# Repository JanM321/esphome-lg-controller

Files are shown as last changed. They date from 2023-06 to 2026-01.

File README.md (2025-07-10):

# ESPHome LG AC Wired Controller
Wired controller for LG Air Conditioners using an ESP32 microcontroller and [ESPHome](https://esphome.io/). It can be used to control an indoor unit from [Home Assistant](https://www.home-assistant.io/).

This has some advantages compared to the [LG ThinQ integration](https://github.com/ollo69/ha-smartthinq-sensors):
* Can override the unit's room temperature thermistor with a Home Assistant temperature sensor.
* Does not depend on LG's ThinQ cloud service.
* Supports units without a Wifi module.
* No annoying sounds from the AC unit when changing settings through the controller.
* More settings and information available (although some settings like display light on/off are available in ThinQ but aren't passed to the wired controller).

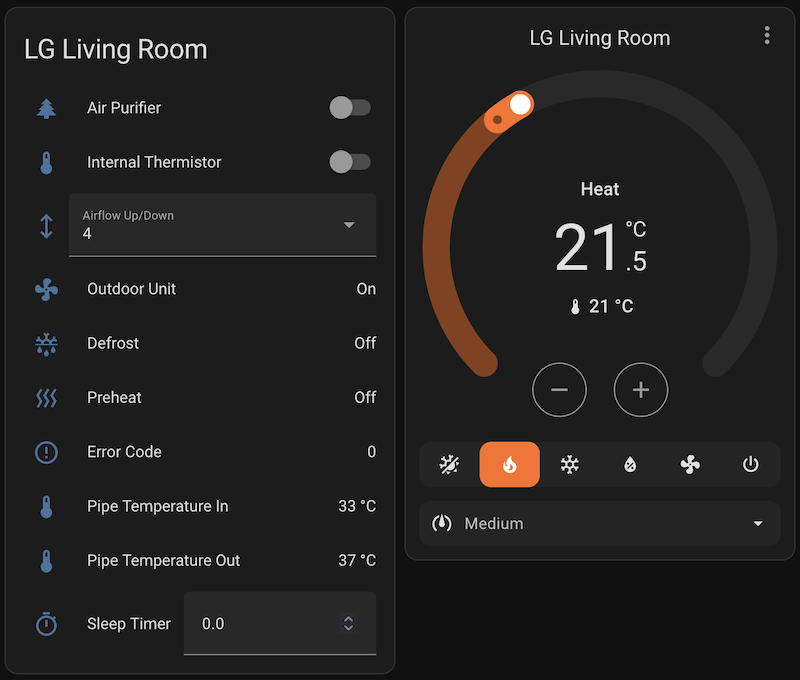
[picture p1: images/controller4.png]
Screenshot of Home Assistant dashboard


# Compatibility
### Supported AC units
If your indoor unit supports the LG PREMTB100 and/or LG PREMTA200 controller, it will very likely be compatible.

The [wiki](https://github.com/JanM321/esphome-lg-controller/wiki) has a list of LG AC units that have been tested with this controller.

### Multiple controllers
It's possible to connect multiple controllers to a single indoor unit, but one of them must be set as 'master' and the others as 'slave'. Since February 2024, this ESPHome controller has experimental support for this. I'm not using this myself, so there might be some issues with this (please report them).

The room temperature sensor is ignored for 'slave' controllers, so if you want to use this controller with an LG controller and use a Home Assistant temperature sensor, the LG controller must be set as 'slave'.

### Details
There seem to be two different protocols that LG AC units and wall controllers use to communicate: 
1. **6-byte protocol**: the controller sends a 6-byte message every four seconds or so and the AC unit responds with a 6-byte message. This is the more basic protocol and likely older because it doesn't support advanced features and settings. An ESPHome implementation of this is available here: https://github.com/Flameeyes/esphome-lg-pqrcuds0
2. **13-byte [protocol](protocol.md)**: the controller sends a 13-byte status message every 20 seconds (or when there's a change in settings) and the AC unit sends a very similar status message every 60 seconds. There are also other message types for more advanced settings. **This is the one implemented here.**

The controller hardware is identical because both use a very slow serial connection (104 bps) over a three-wire cable (Red = 12V, Yellow = Signal, Black = GND). In fact, some LG controllers support both protocols: my LG PREMTB001 controller first tries the 13-byte protocol and if it doesn't receive a response it will switch to the 6-byte protocol. My LG PREMTB100 (newer controller) only supports the 13-byte protocol as far as I can tell.

Wired controllers must be connected to the CN-REMO socket on the indoor unit's PCB (green 3 pin JST-XH connector). Fortunately my wall units came with a short extension cable already plugged into that port so I only had to open up the bottom part of the unit to connect my controller.

Wired controllers using the new protocol only send and receive settings and current temperature. The HVAC unit itself decides when to start/stop active cooling/heating etc based on this. It's possible to use a Home Assistant template sensor as temperature sensor to influence this behavior (see below).

See [protocol.md](protocol.md) for information about the protocol based on reverse engineering the PREMTB001 and PREMTB100 controllers.

# Hardware
There are three different PCB designs. The "hardware-tiny" variant is most popular at this point. The "hardware-FeatherS3" PCB is a more recent addition.

## "hardware" (original, June 2023)
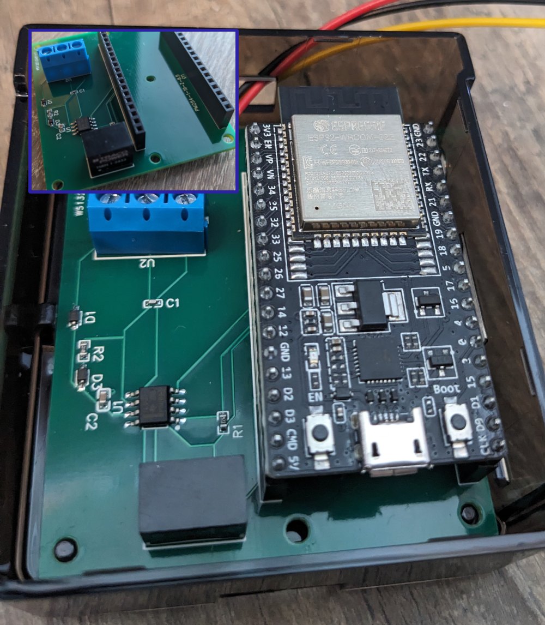
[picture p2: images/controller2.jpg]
PCB in enclosure


You need at least the following parts for each indoor unit:
* PCB. See the original PCB in the [hardware/](hardware/) directory
* ESP32 DevKitC board. I used an Espressif ESP32-DevKitC-32E.
* Cable with JST-XH connector to connect the PCB to the AC. I used an Adafruit 4873 cable.

The `hardware/` PCB I ordered from [PCBWay](https://www.pcbway.com/QuickOrderOnline.aspx).

## "hardware-tiny" (November 2023)
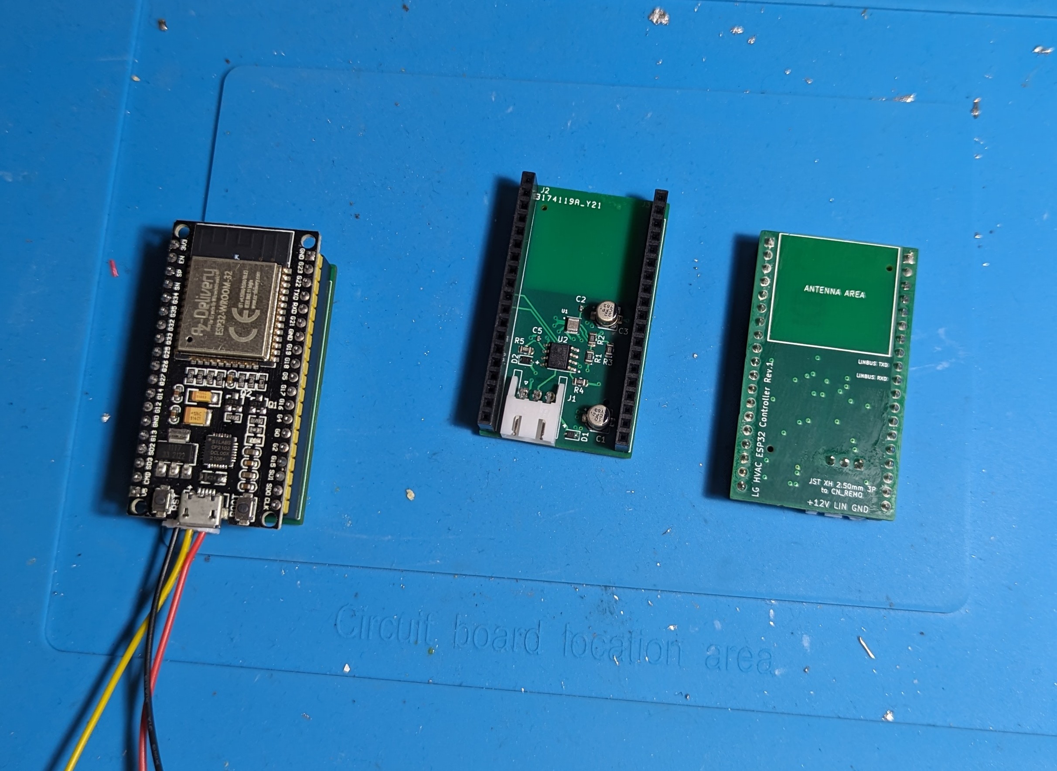
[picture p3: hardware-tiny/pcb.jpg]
Tiny PCB


You need at least the following parts for each indoor unit:
* PCB. See the cheaper and smaller PCB in the [hardware-tiny/](hardware-tiny/) directory.
* ESP32 DevKitC board. I used an Espressif ESP32-DevKitC-32E.
* Cable with JST-XH connector to connect the PCB to the AC. I used an Adafruit 4873 cable.

The `hardware-tiny/` PCB can be ordered from [JLCPCB](https://cart.jlcpcb.com/quote/) (see instructions [here](https://github.com/JanM321/esphome-lg-controller/issues/2#issuecomment-1801803656)).

## "hardware-FeatherS3" (May 2025)

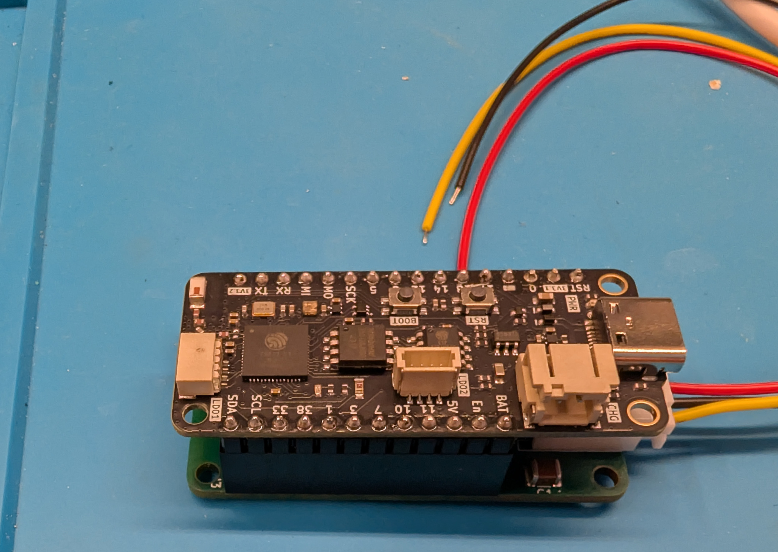
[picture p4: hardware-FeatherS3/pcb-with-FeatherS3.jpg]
PCB with FeatherS3

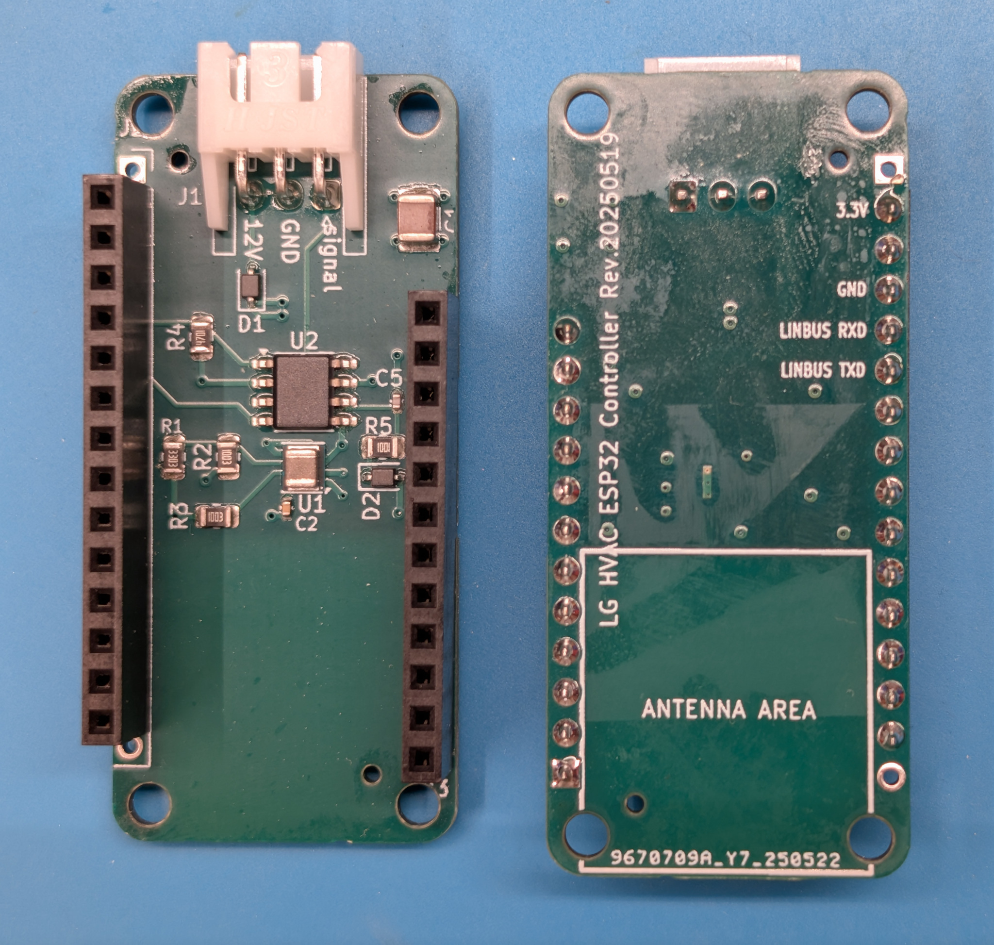
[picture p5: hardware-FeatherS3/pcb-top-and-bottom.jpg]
PCB top and bottom


You need at least the following parts for each indoor unit:
* PCB. See the even smaller PCB in the [hardware-FeatherS3/](hardware-FeatherS3/) directory.
* Unexpected Maker's [ESP32 FeatherS3](https://esp32s3.com/feathers3.html)
* Cable with JST-XH connector to connect the PCB to the AC. I used an Adafruit 4873 cable.

This PCB supports the more modern [FeatherS3 by Unexpected Maker](https://esp32s3.com/feathers3.html), which has a USB-C connector. The FeatherS3 [can be powered from the 3.3V pin](https://help.unexpectedmaker.com/index.php/knowledge-base/can-i-power-my-board-from-the-3v3-pin/), which is what is assumed here. The USB-C connector should not be connected at the same time; if you want to power the FeatherS3 via USB, you should not connect the 3.3V pin.

The `hardware-FeatherS3/` PCB can be ordered from [JLCPCB](https://cart.jlcpcb.com/quote/).

JLCPCB ordering instructions:

* Upload [`GERBER-lg_hvac_esp32.zip`](hardware-FeatherS3/jlcpcb/production_files/GERBER-lg_hvac_esp32.zip) as the gerber file, leave all settings default.
* Enable the `Assembly` option at the bottom of the quote page and proceed.
* Upload [`BOM-lg_hvac_esp32.csv`](hardware-FeatherS3/jlcpcb/production_files/BOM-lg_hvac_esp32.csv) for the bom file and [`CPL-lg_hvac_esp32.csv`](hardware-FeatherS3/jlcpcb/production_files/CPL-lg_hvac_esp32.csv) for placement / cpl

I paid about $50 for five boards, fully assembled, before any shipping and import duties.

*Note: if you use the FeatherS3 PCB, you'll also need to make some changes to `esphome/base.yaml` for ESPHome as part of the next step. See the FeatherS3 comments in that file.*

# ESPHome Firmware
I used the following steps to build the ESPHome firmware, flash it on the device, and add the controller in Home Assistant:
1. Clone this repository and navigate to the `esphome` directory.
2. Install ESPHome command line tools on Linux: https://esphome.io/guides/installing_esphome.html
3. Ensure the Python virtual environment is activated (`source venv/bin/activate`).
4. Copy `template.yaml` to (for example) `lg-livingroom.yaml` and edit the lines marked with `XXX`.
5. Connect the ESP32 DevKitC board to your computer with a micro USB cable. This is only needed the first time, after that it can use OTA updates over wifi.
6. Run `esphome run lg-livingroom.yaml` to build the firmware and upload it to the device.
7. The device can now be added in Home Assistant (Settings => Devices & Services). HA will ask you for the encryption key from the YAML file.
8. Disconnect the micro USB cable.
9. Install the ESP32 DevKitC board on the PCB and connect the PCB to the AC.

If you just want to connect to the device to view the debug logs, use `esphome logs lg-livingroom.yaml`.

# Features
Features currently available in Home Assistant:
* Operation mode (off, auto, cool, heat, dry/dehumidify, fan only).
* Target temperature (0.5°C steps).
* Use of a Home Assistant temperature sensor for room temperature (rounded to nearest 0.5°C). 
* Fan speed (slow, low, medium, high, auto).
* Swing mode (off, vertical, horizontal, both).
* Airflow up/down setting from 0-6 for up to 4 vanes (vane angle, with 0 being default for operation mode).
* Switch for external vs internal thermistor.
* Switch for air purifier (plasma) on/off.
* Switch and binary sensor for Auto Dry (also known as Auto Clean) feature. Used to dry indoor unit when it's turned off after cooling/dehumidifying.
* Sensors for reporting outdoor unit on/off, defrost, preheat, error code.
* Sensors for reporting in/mid/out pipe temperatures (if supported by unit).
* Input field for sleep timer from 0 to 420 minutes (0 turns off the sleep timer).
* Input fields for fan speed installer setting (to fine-tune fan speeds, 0-255 with 0 being factory default). This is installer setting 3 (ESP Setting) on LG controllers.
* Select option for over heating installer setting from 0-4 (to change over heating behavior in heating mode). This is installer setting 15 (Over Heating) on LG controllers.
* YAML options for Fahrenheit mode and 'slave' controller mode.
* Detects & exposes only supported capabilities for the connected indoor unit.

The LG ThinQ app and wireless remote can still be used to change these settings and other settings. They'll be synchronized with this controller.

Unfortunately not all settings are exposed to the wired controller, but if you're interested in a feature and it's supported by the PREMTB100 or PREMTA200 controller, please open an issue and we can consider adding it.

# Tips
* [Issue #43](https://github.com/JanM321/esphome-lg-controller/issues/43) has some information on temperature sensors that work well for this.
* It's possible to use a Home Assistant template sensor as room temperature sensor. I'm [using this](https://gist.github.com/JanM321/b550285713f20231386509b2c227f0b8) to work around some issues with my LG Multi F unit in heating mode.

# PCB (details)
***❗ Update November 2023: This section is for my original PCB in the hardware/ directory. [Florian Brede](https://github.com/florianbrede-ayet) has designed a smaller and cheaper PCB that can be ordered from JLCPCB. It's in the [hardware-tiny/](hardware-tiny/) directory.***

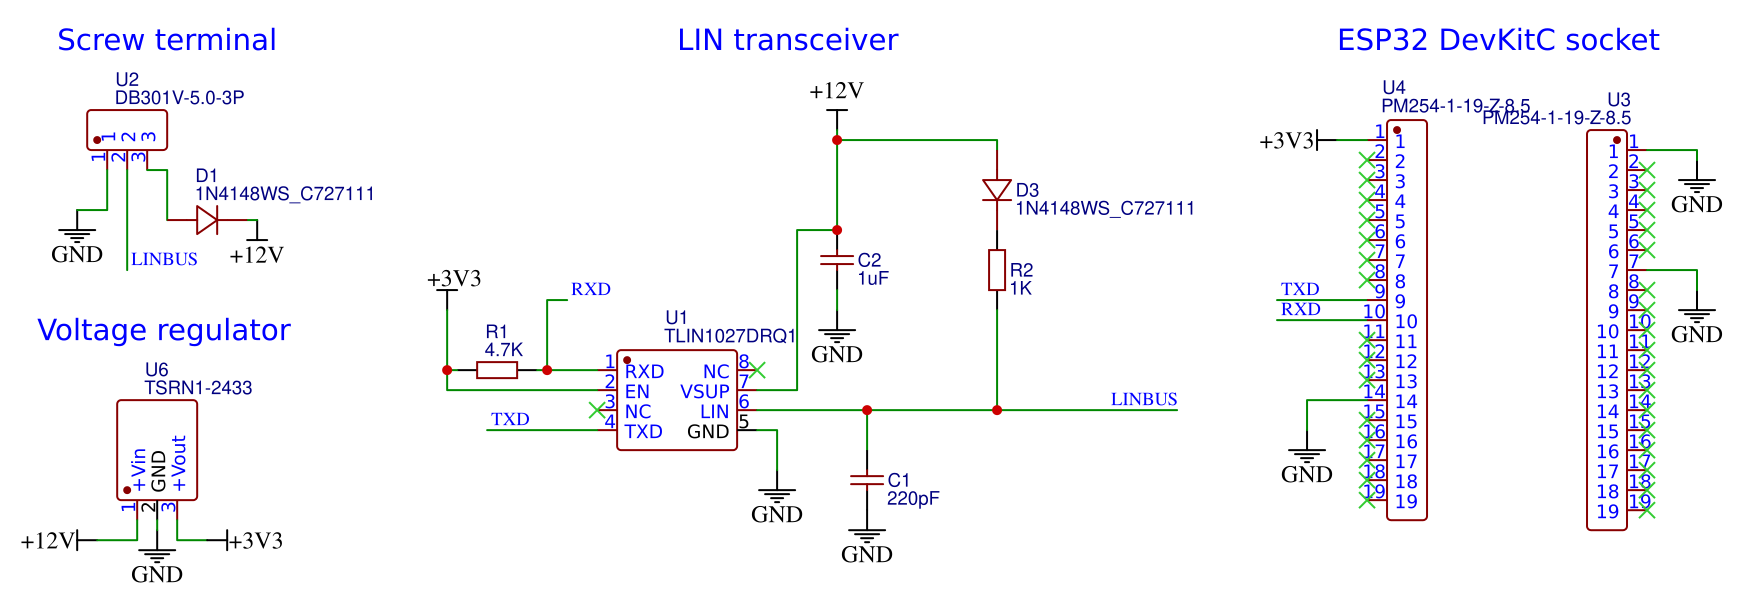
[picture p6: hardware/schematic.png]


See [hardware/](hardware/) for schematic and list of materials. This part was based on the excellent work and research by [@Flameeyes](https://github.com/Flameeyes):
* https://flameeyes.blog/tag/lg/
* https://github.com/Flameeyes/esphome-lg-pqrcuds0

The hardware needs four main components:
1) **Microcontroller**. Similar to their setup, I used an Espressif ESP32-DevKitC-32E board (it has the ESP32-WROOM-32E module).
A devkit module is nice for this because it doesn't need any external components. My PCB has two female pin headers connecting it to the board. This also makes it easy to replace or upgrade if needed.
2) **Transceiver**. This is needed because the AC has a single (12V) signal wire but the microcontroller has separate (lower-voltage) RX/TX pins. I used a [TI TLIN1027DRQ1](https://www.ti.com/product/TLIN1027-Q1/part-details/TLIN1027DRQ1) LIN transceiver. LIN transceivers are typically used in the automotive industry but work well for this too. As [explained](https://flameeyes.blog/2021/06/29/lg-aircon-reversing-part-2-buses-and-cars/) by Flameeyes, it's important to use a LIN transceiver without the "TXD-Dominant Timeout" feature because LG's very slow ~104 bps serial connection can trigger that timeout and this will corrupt the signal.
3) **Voltage regulator**. This is needed because the AC supplies 12V but the microcontroller requires 3.3V. I replaced the voltage regulator part with a [Traco Power TSRN 1-2433](https://www.tracopower.com/int/model/tsrn-1-2433) step-down switching regulator because it doesn't require any external components such as capacitors or inductors. (In hindsight, the [Traco Power TSR 1-2433](https://www.tracopower.com/int/model/tsr-1-2433) might have been better because it's cheaper and has better availability.)
4) **Connector**. To connect the PCB to the AC. I used a screw terminal for this.

My PCB also has some capacitors, resistors and diodes that are based on the TLIN1027DRQ1 data sheet. I'm not sure if these are really necessary but I included them to be safe and it works well. I used SMT components if available because I had the PCBs assembled by [PCBWay](https://www.pcbway.com/). **Update november 2023: the hardware-tiny/ PCB can be ordered from JLCPCB.**

Note: an alternative for the LIN transceiver is the opto-isolator design used here:
* https://github.com/AussieMakerGeek/LG_Aircon_MQTT_interface
* https://www.instructables.com/Hacking-an-LG-Ducted-Split-for-Home-Automation/

# License
This project is licensed under the 0BSD License. See the LICENSE file for details.
This basically means you can use it however you want. Attribution is not required but would be greatly appreciated.

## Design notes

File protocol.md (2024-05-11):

# LG Wall Controller Protocol

Documentation for the protocol used by wired wall controllers. This is largely based on reverse-engineering the LG PREMTB001 controller (some information is based on the newer PREMTB100).
Most of these things haven't been tested with an actual AC unit.

NOTE: as explained in the [README](./README.md), this controller actually supports two different protocols. This only documents the more modern protocol that's used by my own AC.

Some information is based on:
* This post and comments: https://www.instructables.com/Hacking-an-LG-Ducted-Split-for-Home-Automation/
* Corresponding source code: https://github.com/AussieMakerGeek/LG_Aircon_MQTT_interface

## Overview
LG controllers use a (very slow) 104 bps 8N1 serial connection over a three-wire cable (Red = 12V, Yellow = Signal, Black = GND) connected to the CN-REMO port on the indoor unit's PCB.
The HVAC unit and controller will often send the same message twice (or even four times) with a short delay between them, but this is not required.

## Collisions
Collisions on the bus are possible because devices can send at arbitrary times, for example immediately after a setting is changed. My custom controller tries to
prevent this by ensuring the RX pin is high for at least 500 ms before sending. This works well (I haven't seen any collisions in practice) and the LG
controllers seem to do something similar.

My custom controller also checks that each message we send is transmitted uncorrupted and else it tries to send it again. This works because it's a single wire
bus, so the controller always receives its own messages too.

## Message format
Each message is 13 bytes long. The first byte indicates the message type:
| Bits | Description |
| --- | --- |
| `XXX0_0000` | Source of the message<br>1: slave controller (for example `0x28` or `0x2A`)<br>5: master controller (for example `0xA8` or `0xAA`)<br>6: unit (for example `0xC8` or `0xC9`) |
| `000X_X000` | Product type <br>0: ventilation<br>1: AC<br>2: heat exchanger?|
| `0000_0XXX` | Message type (0-7)<br>0: status message<br>1: capabilities message<br>2: settings<br>... see below ... |

The two "product type" bits are always set to `01` for normal HVAC units. This means the (master) controller sends messages with first byte `0xA8` to `0xAF` and the AC unit will send messages `0xC8` to `0xCF`. You can use this to identify the source of a message.

For instance, `0xC8` is a status message sent by the AC unit. `0xAA` is a settings message sent by the controller.

LG controllers send messages with the product type field set to 0 or 2 only when connected to a ventilation product responding with such messages. For example if a heat exchanger unit responds with `0xD0` messages, the LG controllers will switch from sending `0xA8` to `0xB0` messages. This documentation and the ESPHome controller only cover AC units.

The last byte of each message is a checksum, computed by adding up the other bytes and XOR'ing with `0x55`.

## Type 0: Status message (0xA8/0xC8/0x28)
Status messages are used to control all of the basic settings such as operation mode, fan mode, room temperature, etc.

The controller and AC unit will send this when a setting changes. The AC unit will also send this every 60 seconds and 'master' controllers send this every 20 seconds.
| Byte | Bits | Description |
| --- | --- | --- |
| 0 | `XXXX_XXXX` | Message type, `0xA8/0xC8/0x28` |
| 1 | `0000_000X` | Set if settings were changed |
| | `0000_00X0` | On/off<br>0: unit is off<br>1: unit is on |
| | `000X_XX00` | Operation mode<br>0: cooling<br>1: dehumidify<br>2: fan<br>3: auto<br>4: heating |
| | `XXX0_0000` | Fan speed<br>0: low<br>1: medium<br>2: high<br>3: auto<br>4: slow<br>5: low-medium<br>6: medium-high<br>7: power
| 2 | `0000_000X` | If set, controller shows Filter sign |
| | `0000_00X0` | Controller sets this when clearing Filter in settings? |
| | `0000_0X00` | Plasma / air-purifier |
| | `0000_X000` | Humidifier |
| | `000X_0000` | Resistive heater |
| | `00X0_0000` | Swirl |
| | `0X00_0000` | Horizontal swing |
| | `X000_0000` | Vertical swing |
| 3 | `0000_000X` | External ventilation is on |
| | `0000_00X0` | Fan Auto function |
| | `0000_0X00` | Defrost |
| | `0000_X000` | Preheat |
| | `000X_0000` | Active reservation |
| | `0XX0_0000` | Elevation grill setting<br>0: default<br>1: stop<br>2: up<br>3: down |
| | `X000_0000` | Unknown |
| 4 | `0000_XXXX` | Unknown (seems related to central control) |
| | `000X_0000` | Plasma sign blinks if plasma on (unclear what this is for) |
| | `00X0_0000` | Auto addressing (shows IDU address on PREMTB100) |
| | `0X00_0000` | Set by unit in heating mode |
| | `X000_0000` | Related to central control |
| 5 | `0000_000X` | Add 0.5 to setpoint in byte 6 |
| | `0000_00X0` | Energy saving function |
| | `0000_0X00` | Outdoor unit is active |
| | `0000_X000` | Zone 4 on |
| | `000X_0000` | Zone 3 on |
| | `00X0_0000` | Zone 2 on |
| | `0X00_0000` | Zone 1 on |
| | `X000_0000` | Set if installer setting Zone Type is set to New |
| 6 | `0000_XXXX` | Setpoint, stored as `temperature - 15` (example: 4 => 19°C or 19.5°C depending on byte 5)<br>In AI mode: -2 to +2 stored as 0-4 |
| | `00XX_0000` | Thermistor installer setting<br>0: unit<br>1: controller<br>2: 2TH |
| | `XX00_0000` | Ceiling height installer setting<br>0: medium<br>1: low<br>2: high<br>3: very high |
| 7 | `00XX_XXXX` | Room temperature, stored as `(temperature - 10) * 2` (example: 27 => `27 / 2 + 10` => 23.5°C) |
| | `0X00_0000` | Set by AC when any indoor unit is in cooling mode |
| | `X000_0000` | Set by AC when any indoor unit is in heating mode |
| 8 | `0000_0XXX` | Reservation/timer number of minutes, upper bits (see next section) |
| | `00XX_X000` | Reservation/timer type (see next section)<br>0: none<br>1: turn-on reservation<br>2: turn-off reservation<br>3: sleep timer<br>4: clear all reservation data<br>5: simple timer (on/off after N minutes)<br>6-7: unknown |
| | `0X00_0000` | If set, the AC unit will send a batch with all of its settings (other message types below) and clear it. LG controllers set this when powered on. |
| | `X000_0000` | Set temporarily for "release 3 minute delay" installer setting 10 |
| 9 | `XXXX_XXXX` | Reservation/timer number of minutes, lower bits (see next section) |
| 10 | `0000_000X` | Set temporarily for installer setting 1 (test run) |
| | `0000_00X0` | Zone 8 on |
| | `0000_0X00` | Unknown, but always set by PREMTB100 (PREMTB001 sets it too but lets the unit clear it) |
| | | Or for duct units with > 4 zones: zone 7 on |
| | `0000_X000` | Active robot clean |
| | | Or for duct units with > 4 zones: zone 6 on |
| | `000X_0000` | Active auto clean (auto dry) |
| | | Or for duct units with > 4 zones: zone 5 on |
| | `00X0_0000` | Unknown |
| | `0X00_0000` | Set by unit when initializing? |
| | `X000_0000` | Set by controller when initializing or for reservation/Fahrenheit settings (see next sections) |
| 11 | `XXXX_XXXX` | Error value, 0 = no error |
| 12 | `XXXX_XXXX` | Checksum |

### Reservation settings
Timer-related settings use the reservation flag in byte 3 with type + number of minutes stored in bytes 8 and 9.

For example when the controller sets a "simple reservation" to turn on/off after N hours, it stores the reservation type in byte 8 and the number of minutes in byte 9 + the three low bits of byte 8 if value > 255:
```
1 hour : a8 43 00 10 00 00 03 1d 28 3c 00 00 => 0x3c => 60 minutes
7 hours: a8 43 00 10 00 00 03 1d 29 a4 00 00 => 0x100 + 0xa4 => 420 minutes
                  ^              ^^ ^^
```
If a wired controller is connected, it looks like the unit makes it the controller's responsibility to implement these timers and turn the unit on/off.

The sleep timer option uses a different reservation type (3) in byte 8. The sleep timer is the only reservation type that the controller keeps sending regularly with the updated number of minutes. Unlike the other reservation types, the sleep timer can't be emulated with Home Assistant automations because some units use an extra-low fan speed and reduce power usage when the sleep timer is on. This is why the ESPHome controller supports sleep timers natively but not any of the other timers.

The turn-off/turn-on reservations are set based on the target time, but the controller always converts this to number of minutes relative to the current time.

To disable a single reservation or timer, the number of minutes can be set to 0. Reservation type 4 will clear all reservations.

Because multiple reservation types can be active at the same time, the controller also has a way to disable individual ones: byte 10 has bit `0x80` set and then byte 9 has a single bit for each of the following if they're enabled: turn-off reservation (`0x4`), turn-on reservation (`0x8`), sleep timer (`0x10`), and simple timer (`0x20`). My AC unit doesn't send messages like this, it just uses the reservation type with number of minutes > 0 to enable a reservation or timer, and 0 minutes to disable it.

### Fahrenheit mode
Temperature values sent/received are always in Celsius. To switch the unit to Fahrenheit (this affects the displayed temperature), the controller can temporarily set bit `0x80` of byte 10 and then set byte 9 to `0x40`. (Note that this is similar to the mechanism in the previous paragraph.)

Unfortunately LG uses a Fahrenheit/Celsius mapping that's different from what you'd expect. For example, 78°F is ~25.5°C, but LG controllers and units will instead send 26°C for 78°F (even though 26°C is more like 79°F). A value of 25.5°C is treated by the AC as 77°F. The ESPHome controller has code to convert between Fahrenheit, Celsius and "LG-Celsius" in Fahrenheit mode to account for these differences. See [issue #27](https://github.com/JanM321/esphome-lg-controller/issues/27) for more information on this.

## Type 1: Capabilities message (0xC9)
The AC sends this to the controller when it's powered on to tell it which features are supported.
| Byte | Bits | Description |
| --- | --- | --- |
| 0 | `XXXX_XXXX` | Message type, `0xC9` |
| 1 | `0000_0XXX` | Kind of unit?<br>1: cassette<br>2: duct (enables zone settings)<br>4: wall unit<br>(other values unknown) |
| | `0000_X000` | Unknown |
| | `000X_0000` | Supports zone state installer setting |
| | `00X0_0000` | Supports swirl |
| | `0X00_0000` | Supports horizontal swing |
| | `X000_0000` | Supports vertical swing |
| 2 | `0000_000X` | Supports Fan Auto sub function |
| | `0000_00X0` | Supports plasma (air purifier) |
| | `0000_0X00` | Supports humidifier |
| | `0000_X000` | Supports operation mode Auto |
| | `000X_0000` | Supports operation mode AI |
| | `00X0_0000` | Supports operation mode Heating |
| | `0X00_0000` | Supports operation mode Fan |
| | `X000_0000` | Supports operation mode Dehumidify |
| 3 | `0000_000X` | Supports fan speed Auto |
| | `0000_00X0` | Supports fan speed Power |
| | `0000_0X00` | Supports fan speed High |
| | `0000_X000` | Supports fan speed Medium |
| | `000X_0000` | Supports fan speed Low |
| | `00X0_0000` | Supports fan speed Slow |
| | `0X00_0000` | Unknown |
| | `X000_0000` | Supports fan speed Power in heating mode |
| 4 | `0000_000X` | Supports vertical vane control |
| | `0000_00X0` | Supports ESP value installer setting |
| | `0000_0X00` | Supports static pressure installer setting |
| | `0000_X000` | Supports ceiling height installer setting |
| | `00XX_0000` | Unknown |
| | `0X00_0000` | Supports robot clean setting |
| | `X000_0000` | Supports auto clean (auto dry) setting |
| 5 | `0000_000X` | Supports energy saving sub function |
| | `0000_00X0` | Supports override master/slave installer setting |
| | `0000_0X00` | Supports auto change temperature setting |
| | `000X_X000` | Unknown |
| | `00X0_0000` | Half degrees C not supported |
| | `0X00_0000` | Has single vane |
| | `X000_0000` | Has two vanes |
| 6 | `0000_000X` | Supports extra airflow option (presence based?) |
| | `0000_0XX0` | Unknown |
| | `0000_X000` | Supports low-medium fan option |
| | `000X_0000` | Supports medium-high fan option |
| | `00X0_0000` | Supports minimum cooling target temperature of 16 instead of 18 |
| | `XX00_0000` | Unknown |
| 7 | `0000_0X00` | Supports auxiliary heater, installer setting |
| | `000X_X000` | Supports setting for zone = 1 to N (this value) in settings. Unclear what this is for |
| | `X000_0000` | Supports over heating, installer setting 15 |
| 8 | `0000_000X` | Supports pipe temperature setting (installer setting 16 on PREMTB001) |
| | `0000_00X0` | Supports centrigrade installer setting (0.5C or 1C) |
| | `0000_0X00` | Unknown |
| | `0000_X000` | Supports 5-8 zones |
| | `000X_0000` | Supports emergency heater installer setting |
| | `00X0_0000` | Supports group control installer setting |
| | `0X00_0000` | Supports unit information setting |
| | `X000_0000` | Supports clear filter timer in settings |
| 9 | `0000_00X0` | Supports indoor unit address check, installer setting 26 |
| | `0000_0X00` | Supports over cooling, installer setting 27 |
| | `000X_0000` | Supports energy usage setting |
| | `X000_0000` | Supports refrigerant leak detector installation, installer setting 29 |
| 10 | `0000_000X` | Supports DRED (demand response enabling device) |
| | `0000_00X0` | Supports static pressure step, installer setting 32 |
| | `0000_0X00` | Supports indoor unit Wifi AP setting |
| | `0X00_0000` | Supports fan cooling mode thermal off, installer setting 35 |
| | `X000_0000` | Supports use primary heater control, installer setting 36 |
| 11 | `0000_000X` | Supports indoor unit auto start installer setting |
| | `0000_00X0` | Supports AC fan interlocked with ventilation installer setting |
| | `0000_0X00` | Supports himalaya cool sub function |
| | `0000_X000` | Supports monsoon comfort option |
| | `000X_0000` | Supports mosquito away sub function |
| | `00X0_0000` | Supports hum+e sub function (called 'comfort cooling' on PREMTB100) |
| | `0X00_0000` | Unknown |
| | `X000_0000` | Supports simple dry contact installer setting 41 |
| 12 | `XXXX_XXXX` | Checksum |

## Type 2: Settings (0xAA/0xCA)
Type 0xA messages store more advanced settings and are only sent when the AC is powered on or when changing settings.

| Byte | Bits | Description |
| --- | --- | --- |
| 0 | `XXXX_XXXX` | Message type, `0xAA` or `0xCA` |
| 1 | `XXXX_XXXX` | Unit address (see installer setting 2) |
| 2 | `XXXX_XXXX` | Fan speed for Slow fan (see installer setting 3)<br>0: default |
| 3 | `XXXX_XXXX` | Fan speed for Low fan (see installer setting 3)<br>0: default |
| 4 | `XXXX_XXXX` | Fan speed for Medium fan (see installer setting 3)<br>0: default |
| 5 | `XXXX_XXXX` | Fan speed for High fan (see installer setting 3)<br>0: default |
| 6 | `XXXX_XXXX` | Fan speed for Power fan (see installer setting 3)<br>0: default |
| 7 | `0000_XXXX` | Vertical vane position for vane 1<br>0: default for operation mode<br>1: up<br>2-5: ...<br>6: down  |
| | `XXXX_0000` | Vertical vane position for vane 2 |
| 8 | `0000_XXXX` | Vertical vane position for vane 3 |
| | `XXXX_0000` | Vertical vane position for vane 4 |
| 9 | `0000_0XXX` | Auto change temperature setting 1-7 |
| | `X000_0000` | Auxiliary heater, installer setting 25<br>0: not installed<br>1: installed |
| 10 | `XXXX_0000` | Maximum setpoint value, stored as `temperature - 15`. Typically `0xf` => 30°C. |
| | `0000_XXXX` | Minimum setpoint value, stored as `temperature - 15`. Typically `0x1` => 16°C. |
| 11 | `0000_000X` | Dry contact mode installer setting 9<br>1: auto |
| | `0000_00X0` | Zone state installer setting 11<br>0: variable<br>1: fixed |
| | `0000_0X00` | Robot clean auto |
| | `0000_X000` | Auto clean (auto dry) enabled |
| | `XXXX_0000` | Unknown |
| 12 | `XXXX_XXXX` | Checksum |

## Type 3: More settings (0xAB/0xCB)
0xB stores more information and settings (whether Wifi AP mode is on, installer settings, etc).

| Byte | Bits | Description |
| --- | --- | --- |
| 0 | `XXXX_XXXX` | Message type, `0xAB` or `0xCB` |
| 1 | `0000_00XX` | DRED, demand response mode<br>0: off<br>1: DRM 1<br>2: DRM 2<br>3: DRM 3 |
| | `X000_0000` | Set to request this message type from the other side (works both ways). For example, if the controller sends `AB 80 ..`, the unit will immediately send `CB 00 ..`. Messages are otherwise the same. |
| 2 | `0000_00XX` | Setting zone = 1-3 in settings menu will set these bits to that number. Unclear what this setting is for. |
| | `00XX_X000` | Over heating, installer setting 15<br>0: default for unit<br>1: +4°C / +6°C<br>2: +2°C / +4°C<br>3: -1°C / +1°C<br>4: -0.5°C / +0.5°C<br>Note: the LG controllers only show option 4 in Fahrenheit mode (where it's -1F/+1F) and some only in dual setpoint mode, but a custom controller can send it in Celsius mode too. |
| | `XX00_0000` | Over cooling, installer setting 27<br>0: +0.5°C / -0.5°C<br>1: +6°C / +4°C<br>2: +4°C / +2°C<br>3: +1°C / -1°C |
| 3 | `XXXX_XXXX` | Pipe temperature In (see table below) |
| 4 | `XXXX_XXXX` | Pipe temperature Out (see table below) |
| 5 | `XXXX_XXXX` | Pipe temperature Mid (see table below) |
| 6 | `0000_00X0` | Oil change warning |
| | `0000_0X00` | Centrigrade control, installer setting 17<br>0: 1°C<br>1: 0.5°C |
| | `0000_X000` | Emergency heater, installer setting 18<br>0: don't use<br>1: use |
| | `0X00_0000` | Emergency heater, installer setting 18, fan speed<br>0: fan off<br>1: fan on |
| | `X000_0000` | Function setting for group control, installer setting 19<br>0: not in use<br>1: in use |
| 7 | `0X00_0000` | Indoor unit Wifi Access Point (AP) mode |
| 8 | `0000_XXXX` | Model info, outdoor unit (see table in PREMTB001 manual) |
| | `XXXX_0000` | Model info, indoor unit (see table in PREMTB001 manual) |
| 9 | `0000_XXXX` | Model info, capacity field (see table in PREMTB001 manual) |
| | `000X_0000` | Refrigerant leak detector, installer setting 29<br>0: not installed<br>1: installed |
| | `XX00_0000` | Fan operation in cooling mode and thermal off conditions, installer setting 35<br>0: fan low<br>1: fan off<br>2: fan setting |
| 10| `0000_XXXX` | Static pressure step, installer setting 32 (0-11) |
| | `XXXX_0000` | Number of zones configured for duct units (Zone Number installer setting) |
| 11| `0000_XXXX` | Emergency heater, installer setting 18, low ambient heating operation (0-15) |
| 12 | `XXXX_XXXX` | Checksum |

### Pipe Temperature Values
Bytes 3-5 contain pipe temperature values. A higher value indicates a lower temperature. Below are the byte values mapped to °C (from PREMTB100). For example, a value of 0x78 indicates 23°C. 
| | 0x0  | 0x1  | 0x2  | 0x3  | 0x4  | 0x5  | 0x6  | 0x7  | 0x8  | 0x9  | 0xA  | 0xB  | 0xC  | 0xD  | 0xE  | 0xF  |
| ---- | ---- | ---- | ---- | ---- | ---- | ---- | ---- | ---- | ---- | ---- | ---- | ---- | ---- | ---- | ---- | ---- |
| 0x00 | \- | \- | \- | \- | \- | \- | \- | \- | \- | \- | 108  | 104  | 101  | 100  | 98 | 95 |
| 0x10 | 93 | 91 | 89 | 87 | 85 | 84 | 82 | 81 | 79 | 78 | 76 | 75 | 74 | 73 | 72 | 71 |
| 0x20 | 70 | 68 | 68 | 67 | 66 | 65 | 64 | 63 | 62 | 61 | 60 | 60 | 59 | 58 | 57 | 57 |
| 0x30 | 56 | 55 | 55 | 54 | 53 | 53 | 52 | 52 | 51 | 50 | 50 | 49 | 49 | 48 | 47 | 47 |
| 0x40 | 46 | 46 | 45 | 45 | 44 | 44 | 43 | 43 | 42 | 42 | 41 | 41 | 40 | 40 | 39 | 39 |
| 0x50 | 39 | 38 | 38 | 37 | 37 | 36 | 36 | 36 | 35 | 35 | 34 | 34 | 33 | 33 | 33 | 32 |
| 0x60 | 32 | 31 | 31 | 31 | 30 | 30 | 30 | 29 | 29 | 29 | 28 | 28 | 27 | 27 | 27 | 26 |
| 0x70 | 26 | 26 | 25 | 25 | 24 | 24 | 24 | 23 | 23 | 23 | 22 | 22 | 22 | 21 | 21 | 21 |
| 0x80 | 20 | 20 | 20 | 19 | 19 | 19 | 18 | 18 | 18 | 17 | 17 | 17 | 16 | 16 | 16 | 15 |
| 0x90 | 15 | 15 | 14 | 14 | 14 | 13 | 13 | 13 | 12 | 12 | 12 | 11 | 11 | 11 | 10 | 10 |
| 0xA0 | 10 | 9 | 9 | 9 | 8 | 8 | 8 | 7 | 7 | 6 | 6 | 6 | 5 | 5 | 5 | 4 |
| 0xB0 | 4 | 4 | 3 | 3 | 3 | 2 | 2 | 2 | 1 | 1 | 0 | 0 | 0 | 0 | 0 | \-1  |
| 0xC0 | \-1  | \-2  | \-2  | \-2  | \-3  | \-3  | \-4  | \-4  | \-5  | \-5  | \-5  | \-6  | \-6  | \-7  | \-7  | \-8  |
| 0xE0 | \-8  | \-9  | \-9  | \-9  | \-10 | \-10 | \-11 | \-11 | \-12 | \-12 | \-13 | \-14 | \-14 | \-15 | \-15 | \-16 |
| 0xE0 | \-16 | \-17 | \-18 | \-18 | \-19 | \-20 | \-20 | \-21 | \-22 | \-22 | \-23 | \-24 | \-25 | \-26 | \-27 | \-28 |
| 0xF0 | \-29 | \- | \- | \- | \- | \- | \- | \- | \- | \- | \- | \- | \- | \- | \- | \- |

## Type 4: More status information (0xAC/0xCC)
The wall controller sends these regularly and apparently some AC units do this too, but I've never seen this from my unit.

| Byte | Bits | Description |
| --- | --- | --- |
| 0 | `XXXX_XXXX` | Message type, `0xAC/0xCC/2C` |
| 1 | `XXXX_XXXX` | Filter time left in hours (low bits). Combined with value in byte 2.<br>Example: `CC.AB.01 => 0x1AB => 427 hours left` |
| 2 | `0000_XXXX` | Filter time left in hours (high bits) |
| | `0X00_0000` | Occupancy status |
| | `X000_0000` | Dual setpoint mode |
| 3-5 | `XXXX_XXXX` | Power Consumption in kWh. Example: `64.91.29 => 64912.9 kWh` |
| 6 | `0XXX_XXXX` | Setpoint in degrees C, integer part. Used for the high setpoint in dual setpoint mode |
| 7 | `0XXX_XXXX` | Setpoint in degrees C, integer part. Used for the low setpoint in dual setpoint mode |
| | `X000_0000` | Set if settings were changed. This is similar to the bit in byte 1 for Type 0 status messages |
| 8 | `0000_XXXX` | Fractional part for setpoint in byte 7 (for example `5 => 0.5C`) |
| | `XXXX_0000` | Fractional part for setpoint in byte 6 |
| 9 | `XXXX_XXXX` | Room temperature value (from controller) or unit temperature (from AC). Stored as `temperature * 2` (example: `0x2B => 21.5C`). PREMTB100 sends this but PREMTB001 always sends 0. |
| 10 | `XXXX_XXXX` | Deadband for dual setpoint mode (example: `0x25 => 2.5C`) |
| 11 | `0000_000X` | Himalaya Cooling |
| | `0000_00X0` | Mosquito Away |
| | `0000_0X00` | Comfort Cooling |
| 12 | `XXXX_XXXX` | Checksum |

## Type 5: Advanced settings (0xAD/0xCD)
My unit sends this after power on with all zeroes. The wall controller uses it for installer settings.
```
Set 25 (auxiliary heater) to duct-type:          ad 04 ...
Set 36 (use primary heater control) to 1:        ad 40 ...
Set 38 (fan interlocked with ventilation) to 1:  ad 02 ...
Set 39 (indoor unit auto start) to 1:            ad 01
Set 41 (simple dry contact setting) to 3:        ad 00 00 00 00 00 03 00 00 00 00 00 ..
```

## Type 6: More settings or status information (0xAE/0xCE)
The format here is a bit different, with the second byte as additional message type (probably because they ran out of message types).
```
CE.00... => extended capabilities message? unit sends this with available settings

CE.10... => used to set settings
Set 46 (fan continuous) to 1:                        ae 10 00 00 02 00 00 00 00 00 00 00 ..
Set 47 (outdoor unit function) to 1:                 ae 10 00 00 00 10 00 00 00 00 00 00 ..
Set 48 (silent mode) to 2:                           ae 10 00 02 00 00 00 00 00 00 00 00 ..
Set 49 (defrost mode) to 3:                          ae 10 00 30 00 00 00 00 00 00 00 00 ..
Set 51 (temperature-based fan speed auto) to 1:      ae 10 00 00 04 00 00 00 00 00 00 00 ..
Set 52 (CN_EXT setting) to 5:                        ae 10 00 00 50 00 00 00 00 00 00 00 .. 
Set 56 (outdoor unit cycle priority) to 1 (standby): ae 10 00 00 00 00 10 00 00 00 00 00 ..
Set it to 2 (cool) with step 3:                      ae 10 00 00 00 00 07 00 00 00 00 00 ..
Set it to 2 (cool) with step 4:                      ae 10 00 00 00 00 09 00 00 00 00 00 ..
Set 60 (outdoor unit cycle priority) to 1 (special): ae 10 00 00 00 00 20 00 00 00 00 00 ..
Set 57 (outdoor temp for heating stages) to 1:       ae 10 00 00 00 00 40 00 00 00 00 00 ..
Set it to 3 with 27.5C:                              ae 10 00 00 00 00 00 00 5b 00 00 00 .. => 0x1b = 27, other bit is for 0.5

CE 11... => used for air quality monitoring values?
```
The `AE 80` / `CE 80` message is a newer, additional status message that the PREMTB100 controller and some units send regularly.
```
AE.80.3C.0F.17.00.2A.74.02.00.12.04.13
- byte 2:      humidity (0x3C => 60%)
- bytes 3-4:   fan operation time (0x0f17 => 3863 hours)
- bytes 6-7:   IDU (indoor unit) operation time (0x2a74 => 10868 hours)
- byte 8:      PREMTB100 always sets bit 2 (unknown)
- bytes 10-11: room temperature with 0.1 degrees precision (0x12 + 0x04 => 18 + 0.4 => 18.4C)
- byte 12:     checksum
```

## Type 7: More status information (0xAF/0xCF)
Used by newer units and controllers. Contains unit's current power usage among other things. Some examples from PREMTB100:
```
CF.00.12.34.56.00.00.00.00.00.00.00.3E => 123.5 kW
CF.00.98.76.54.00.00.00.00.00.00.00.64 => 987.7 kW
CF.00.AB.CD.EF.00.00.00.00.00.00.00.63 => 1123.5 kW
```

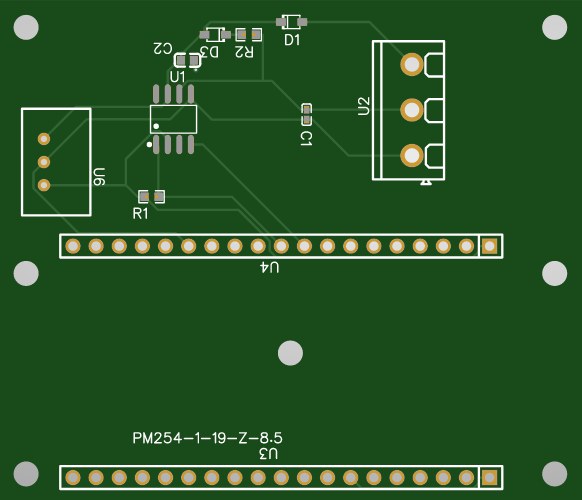
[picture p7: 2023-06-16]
hardware/pcb-top.png

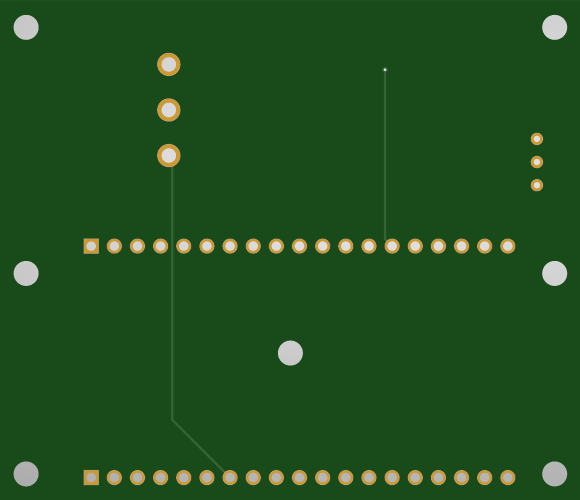
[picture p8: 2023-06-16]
hardware/pcb-bottom.png

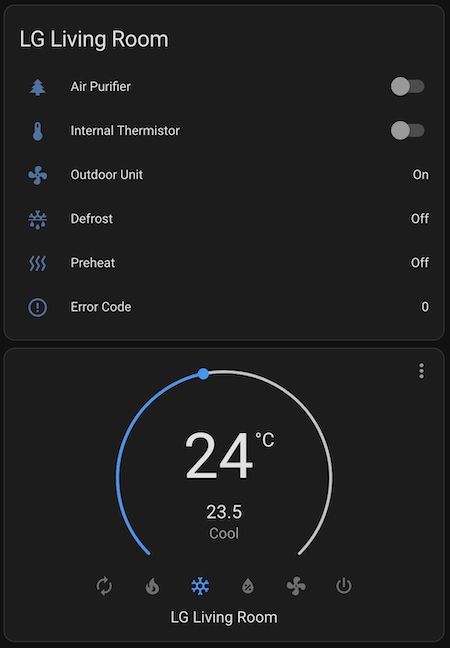
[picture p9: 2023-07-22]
images/controller3.png

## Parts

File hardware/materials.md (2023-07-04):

# Materials

## PCB components

| Designator | Part | LCSC Part |
| --- | --- | --- |
| C1 | YAGEO CC0402KRX7R9BB221 (MLCC, 220pF, 50V) | C107025 |
| C2 | Samsung CL10A105KB8NNNC (MLCC, 1uF, 50V) | C15849 |
| D1, D3 | TWGMC 1N4148WS | C727111 |
| R1 | YAGEO RC0603FR-074K7L (4.7kΩ) | C99782 |
| R2 | YAGEO RC0603FR-071KL (1kΩ) | C22548 |
| U1 | TI TLIN1027DRQ1 (LIN transceiver) | C2870086 |
| U2 | DIBO DB301V-5.0-3P (3p screw terminal) | C395881 |
| U3, U4 | HCTL HDR-TH_19P-P2.54-V-F (2.54mm 19p female pin header) | C2897382 | 
| U6 | Traco Power TSRN 1-2433 (3.3V DC/DC converter) - see note below | - |

Note: next time I'd consider the Traco Power [TSR 1-2433](https://www.tracopower.com/int/model/tsr-1-2433) instead of the [TSRN 1-2433](https://www.tracopower.com/int/model/tsrn-1-2433) because it's cheaper and has better availability.

## Other
* Espressif ESP32-DEVKITC-32E (with ESP32-WROOM-32E module)
* Adafruit 4873, 2.5mm Pitch 3-pin JST XH Compatible cable
* Adafruit 2359, Raspberry Pi A+ Case - Smoke Base w/ Clear Top

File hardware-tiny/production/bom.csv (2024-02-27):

Designator | Footprint | Quantity | Value | LCSC Part #
C1 | CP_Elec_4x5.4 | 1 | 10uF | C401619
C2 | 0402 | 1 | 3.3nF | C26404
C5 | 0402 | 1 | 220pF | C343058
D1, D2 | D_SOD-323 | 2 | 1N4148WS | C727111
J1 | JST_XH_S3B-XH-A-1_1x03_P2.50mm_Horizontal | 1 | JST_XH_S3B-XH-A-1_01x03 | C157928
J2 | PinSocket_1x19_P2.54mm_Vertical | 1 | Conn_01x19_Female_1_to_19 | C2932678
J3 | PinSocket_1x19_P2.54mm_Vertical | 1 | Conn_01x19_Female_20_to_38 | C2932678
R1 | 0805 | 1 | 330k | C17629
R2, R3 | 0805 | 2 | 100k | C149504
R4 | 0805 | 1 | 4.7k | C17673
R5 | 0805 | 1 | 1k | C17513
U1 | Texas_SIL0008D_MicroSiP-8-1EP_2.8x3mm_P0.65mm_EP1.1x1.9mm_ThermalVias | 1 | TPS82130 | C473914
U2 | SO-8_3.9x4.9mm_P1.27mm | 1 | TJA1027 | C194371

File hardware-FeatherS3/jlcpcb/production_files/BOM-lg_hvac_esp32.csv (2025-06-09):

Comment | Designator | Footprint | LCSC | Quantity
100k | R2,R3 | R_0805_2012Metric | C149504 | 2
JST_XH_S3B-XH-A-1_01x03 | J1 | JST_XH_S3B-XH-A-1_1x03_P2.50mm_Horizontal | C157928 | 1
1k | R5 | R_0805_2012Metric | C17513 | 1
330k | R1 | R_0805_2012Metric | C17629 | 1
4.7k | R4 | R_0805_2012Metric | C17673 | 1
TJA1027 | U2 | SOIC-8_3.9x4.9mm_P1.27mm | C194371 | 1
3.3nF | C2 | C_0402_1005Metric | C26404 | 1
Conn_01x12 | J3 | PinSocket_1x12_P2.54mm_Vertical | C2897375 | 1
220pF | C5 | C_0402_1005Metric | C343058 | 1
TPS82130 | U1 | Texas_SIL0008D_MicroSiP-8-1EP_2.8x3mm_P0.65mm_EP1.1x1.9mm_ThermalVias | C473914 | 1
Conn_01x16 | J2 | PinSocket_1x16_P2.54mm_Vertical | C66987 | 1
1N4148WS | D1,D2 | D_SOD-323 | C727111 | 2
10uF | C1 | C_1210_3225Metric | C92834 | 1

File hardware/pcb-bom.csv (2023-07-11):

ID | Name | Designator | Footprint | Quantity | Manufacturer Part | Manufacturer | Supplier | Supplier Part | Price
1 | 4.7K | R1 | R0603 | 1 | RC0603FR-074K7L | YAGEO(国巨) | LCSC | C99782 | 0.001
2 | TLIN1027DRQ1 | U1 | SOIC-8_L4.9-W3.9-P1.27-LS6.0-BL | 1 | TLIN1027DRQ1 | TI(德州仪器) | LCSC | C2870086 | 3.172
3 | DB301V-5.0-3P | U2 | CONN-TH_DB301V-5.0-3P | 1 | DB301V-5.0-3P-BU-S | DIBO(地博电气) | LCSC | C395881 | 0.139
4 | TSRN1-2433 | U6 | PWRM-TH_TSRN1-2433 | 1 | TSRN1-2433 | null | LCSC | C9900016329
5 | PM254-1-19-Z-8.5 | U3,U4 | HDR-TH_19P-P2.54-V-F | 2 | PM254-1-19-Z-8.5 | HCTL(华灿天禄) | LCSC | C2897382 | 0.272
6 | 1uF | C2 | C0603 | 1 | CL10A105KB8NNNC | SAMSUNG(三星) | LCSC | C15849 | 0.005
7 | 1K | R2 | R0603 | 1 | RC0603FR-071KL | YAGEO(国巨) | LCSC | C22548 | 0.001
8 | 1N4148WS_C727111 | D3,D1 | SOD-323_L1.8-W1.3-LS2.5-RD | 2 | 1N4148WS | TWGMC(台湾迪嘉) | LCSC | C727111 | 0.007
9 | 220pF | C1 | C0402 | 1 | CC0402KRX7R9BB221 | YAGEO(国巨) | LCSC | C107025 | 0.001

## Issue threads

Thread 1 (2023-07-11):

Pick and Placement Centroid file

dncbert, 2023-07-11:
Not really an issue... just not sure how else to reach out.

I appreciate the work that you put into this project. I was able to follow your plans and build a breadboard version of this project. It works great although soldering the TI Lin Receiver pushed the boundaries of my soldering skills.

I would like to order a more polished project board from PCBWay. I was able to use the gerber file in the repository for the board layout. I would also like them to install the components if possible. In that process, they requested a centroid file to delineate the location of the components. I am a total novice at this so I do not know how to generate the file. You mentioned in your writeup that you also had PCBWay build your board. Would you happen to have a Centroid file? And if so, are you willing to share it?

Thanks,

Daryl

JanM321, 2023-07-11:
> I appreciate the work that you put into this project. I was able to follow your plans and build a breadboard version of this project. It works great although soldering the TI Lin Receiver pushed the boundaries of my soldering skills.

I was hoping others would be able to use this so that's really great to hear. If you don't mind sharing, which LG AC model are you using it with?

> I would like to order a more polished project board from PCBWay. I was able to use the gerber file in the repository for the board layout. I would also like them to install the components if possible. In that process, they requested a centroid file to delineate the location of the components. I am a total novice at this so I do not know how to generate the file. You mentioned in your writeup that you also had PCBWay build your board. Would you happen to have a Centroid file? And if so, are you willing to share it?

I added it as pcb-placement.csv. I also added pcb-bom.csv for the list of components. Thanks for asking, it is more complete this way.

JanM321, 2023-07-11:
Two more things:

* These CSVs were exported from EasyEDA Designer, the tool I used for the hardware design. I'm not sure if they're standard CSV files, but EasyEDA is pretty popular and PCBWay accepted them.

* PCBWay told me their supplier didn't have a lot of TSRN 1-2433 components in stock (when I ordered in May). If they can't get them anymore it's probably fine to use a TSR 1-2433 instead, but I haven't tested this.

dncbert, 2023-07-12:
Thanks for sharing the pick and placement file. I had managed to create the bom file from your parts list.

I have a ten year old single unit LG heat pump with wall mounted indoor unit. Model# AS-W123MMM9. I added a wall thermostat (PREMTB10U) about eight years ago. I have replaced the wall thermostat with this esphome controller.

I am curious whether you have the same thermostat and if so, have you tried running the esphome controller along side the wall thermostat. i.e. in some kind of master-slave configuration. I would interested in that setup to allow guests to make adjustments at the wall when needed.

jourdant, 2023-07-16:
Might be worth me opening another issue on this to discuss further - but I have a single AC unit outside ducted to multiple zones. Each zone has its own PREMTB001 thermostat. Ideally what I'd like to do is have the ESP32 sitting on the network/controller interface to reflect the state of each zone inside Home Assistant. On top of that I'd like to be able to inject control messages back to the relevant zones and show on the panels too.

From everything I've read in your repo and others, it seems that this should be possible. There may need to be some code changes required as you mentioned above for it running as a slave device for example.

I'm also looking at merging your schematic with this schematic https://oshwlab.com/quickstar77/m5sensorshield so that I can build a single shield for an [M5 Atom Lite](https://shop.m5stack.com/products/atom-lite-esp32-development-kit) device. It's small and works nicely with esphome too.

Would you have any pointers on changes to the library (if needed) for multiple zones or anything else I've mentioned?

Really grateful for the work you've done here so far.

JanM321, 2023-07-16:
@jourdant Are most of your PREMTB001 thermostats for the zones in slave mode? Or can there be multiple master controllers if they're for separate zones?

I haven't paid a lot of attention to zones so far because I'm not familiar with them. [This blog post](https://www.instructables.com/Hacking-an-LG-Ducted-Split-for-Home-Automation/) and the comments have some information but there it sounds like they use one controller where each zone just has a boolean on/off flag? But you instead have one controller per zone where you select the zone in the settings?

I still have the setup to hook up my PREMTB001 to a laptop so I may poke at that a little today because now I'm curious how that mode affects the protocol :)

> I'm also looking at merging your schematic with this schematic https://oshwlab.com/quickstar77/m5sensorshield so that I can build a single shield for an [M5 Atom Lite](https://shop.m5stack.com/products/atom-lite-esp32-development-kit) device. It's small and works nicely with esphome too.

I'm using an M5 Atom Lite as ESPHome [bluetooth proxy](https://esphome.github.io/bluetooth-proxies/) for the temperature sensors and I've had the same thought. My current setup works great so it's hard to justify doing the work for me, but if you manage to get it working I'd love to hear about it.

jourdant, 2023-07-16:
Awesome! I'm new to building PCBs and I know it's a fairly ambitious project to start with, but given I have two references to work from and I just need to combine them - how hard can it be? 😅 I'll definitely make it all available when I've got it working.

I haven't had a chance to look at the zones and whether they are master or slave in the configuration. I need to open the installer mode and figure that out.

Am I right in thinking that we could also be impersonating other devices on the network of controllers to change settings? I need to do a bit more reading on the protocol to understand it more.

Also I know the built in thermistor per panel is not ideal, but I'd like to still collect that data too.

JanM321, 2023-07-16:
> Am I right in thinking that we could also be impersonating other devices on the network of controllers to change settings? I need to do a bit more reading on the protocol to understand it more.

Fortunately the protocol is pretty simple and forgiving in my experience. There are multiple message types and if a controller or the AC unit sends a message, all other devices on the same bus will update their state based on it. Worth checking if your controllers are on the same bus or separate ones (each connected to some kind of global controller or something).

I updated protocol.md with an undocumented zone setting in the settings menu. I'm not sure what this is for but I can set it to 1-3. From what I can tell zones are usually just open/closed though.

JanM321, 2023-07-16:
Oh it's also possible you just have multiple indoor units connected to a single outdoor unit. In that case each indoor unit has its own master controller and communication bus. That's similar to my multi split setup.

jourdant, 2023-07-16:
> Oh it's also possible you just have multiple indoor units connected to a single outdoor unit. In that case each indoor unit has its own master controller and communication bus. That's similar to my multi split setup.

Ohhh it could actually be this. It's ducted so I'm not actually sure what is in the walls. All I know is that I have a single outdoor unit outside with model number ARUN040GSS0. So potentially we're saying that there are separate indoor units with their own controllers (which in this case would all be masters), but they'd all be attached to the single outdoor unit?

JanM321, 2023-07-16:
Correct. A quick search suggests that's indeed a multi split outdoor unit.

Question is which controller protocol is used by the indoor units, the one implemented here or the one implemented [in this repo](https://github.com/Flameeyes/esphome-lg-pqrcuds0) because the PREMTB001 supports both. The hardware is the same so you could also just try both of them, but I don't know if the other protocol supports connecting multiple controllers.

Closed 2023-07-11.

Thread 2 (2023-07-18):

M5 Atom Lite target

jourdant, 2023-07-18:
@JanM321 I'll keep updating this thread going forward as I had pretty much hijacked the other closed issue. For reference in case anyone else is reading: #1.

I had another idea which is potentially a little ambitious (and completely out of my skill range). It would be cool to potentially add a lipo battery to the circuit and have it trickle charge over the 12v supply from the unit. I understand that the 12v on the interface is probably very sensitive and probably not designed to run even an ESP32 off it - but if we could trickle charge a battery and supplement the 12v interface that could be interesting. Alternatively a super small solar cell could potentially charge that battery slowly? What are your thoughts on powering this from the 12v line even without the battery?

I have a test PREMTB001 that I wired up to a 12v power supply and also used a buck converter to 5v for the Atom lite. Unfortunately because there is no unit attached to it (and I haven't got the emulator hooked up to a TTL+LIN adapter) I haven't made any headway there other than being able to power them both.

I am not in the house with the multiple PREMTB001 panels yet, but should be in the next couple of weeks. So I can't easily test them to see if they are all in master configuration, or if this is some kind of master/slave + zone configuration. In the meantime, I am working on adding your design onto the layout of the M5 Atom Lite.

JanM321, 2023-07-18:
> What are your thoughts on powering this from the 12v line even without the battery?

My design does power everything from the 12V line.

I'm not sure how much current you can draw but I think it's possible to connect multiple controllers and the latest ones have color LCD screens (see PREMTB100) so one ESP32 should be fine. I haven't tested this with multiple controllers though. My firmware also doesn't enable the bluetooth proxy feature that ESPHome supports because I didn't want to complicate the design and use more power than necessary.

jourdant, 2023-07-30:
Bit of an update - my progress on learning PCB design isn't moving fast enough so for this one I thought I'd list a quick gig on fiverr (a risk I know 😅).  The requirements were to keep the SHT40 as in the reference size design (so it can be used instead of thermistor if you don't want an external temperature sensor in the room) and to merge in your design including the use of the 12v line for power.

I also had the JST-XH 3-pin socket added on there so that in theory you could build a splitter cable and use the existing plugs that the LG units are using.

I've had a look as much as I can at the spec and it looks ok, but I'm open to someone else with better PCB knowledge taking a look before I get a small prototype run done.

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

jourdant, 2023-09-02:
Just an update - I've had some sample PCBs made up and set up a basic esphome config with:

```
uart:
  tx_pin: GPIO19
  rx_pin: GPIO22
  baud_rate: 104
  debug:
    direction: BOTH
    dummy_receiver: true
    after:
      delimiter: "\n"
    sequence:
      - lambda: UARTDebug::log_string(direction, bytes);
```

I haven't plugged it into the actual aircon unit yet, but I do have it plugged into my spare PREMTB001 that I have on a 12v power brick and I'm seeing data coming in from the LIN transceiver! I haven't made any particular sense of what's coming yet, but I am seeing the messages sent every couple of seconds or so. So far so good.

```
[14:14:53][D][uart_debug:158]: <<< "\x94\x00\x00\x00\x00\xC1"
[14:14:55][D][uart_debug:158]: <<< "\x94\x00\x00\x00\x00\xC1"
[14:14:57][D][uart_debug:158]: <<< "\x94\x00\x00\x00\x00\xC1"
[14:14:59][D][uart_debug:158]: <<< "\x94\x00\x00\x00\x00\xC1"
[14:15:01][D][uart_debug:158]: <<< "\x05\x14\"\x00 \x0E"
[14:15:03][D][uart_debug:158]: <<< "\x05\x15!\x00 \x0E"
[14:15:06][D][uart_debug:158]: <<< "\x05\x15\"\x00 \t"
[14:15:08][D][uart_debug:158]: <<< "\x05\x16\"\x00 \b"
[14:15:10][D][uart_debug:158]: <<< "\x05\x16r\x00 \xF8"
[14:15:12][D][uart_debug:158]: <<< "\x05\x16r\x00 \xF8"
[14:15:14][D][uart_debug:158]: <<< "\x05\x16r\x00 \xF8"
[14:15:16][D][uart_debug:158]: <<< "\x05\x172\x00 ;"
[14:15:18][D][uart_debug:158]: <<< "\x05\x172\x00 ;"
[14:15:20][D][uart_debug:158]: <<< "\x15\x17\x02\x00 \e"
[14:15:22][D][uart_debug:158]: <<< "\x15\x17\x02\x00 \e"
[14:15:24][D][uart_debug:158]: <<< "\x14\x17\x02\x00 \x18"
[14:15:27][D][uart_debug:158]: <<< "\x14\x17\x02\x00 \x18"
[14:15:29][D][uart_debug:158]: <<< "\x14\x17\x02\x00 \x18"
[14:15:31][D][uart_debug:158]: <<< "E\x17.\x00 \xFF"
[14:15:33][D][uart_debug:158]: <<< "E\x18.\x00 \xFE"
[14:15:35][D][uart_debug:158]: <<< "D\x18.\x00 \xFF"
[14:15:37][D][uart_debug:158]: <<< "D\x18.\x00 \xFF"
[14:15:39][D][uart_debug:158]: <<< "D\x18.\x00 \xFF"
[14:15:41][D][uart_debug:158]: <<< "5\x18)\x00 \xC3"
[14:15:43][D][uart_debug:158]: <<< "5\x18)\x00 \xC3"
[14:15:45][D][uart_debug:158]: <<< "4\x18)\x00 \xC0"
[14:15:47][D][uart_debug:158]: <<< "4\x18)\x00 \xC0"
[14:15:50][D][uart_debug:158]: <<< "%\x18)\x00 \xD3"
[14:15:52][D][uart_debug:158]: <<< "%\x18)\x00 \xD3"
[14:15:54][D][uart_debug:158]: <<< "$\x18)\x00 \xD0"
[14:15:56][D][uart_debug:158]: <<< "\x05\x182\x00 :"
[14:15:58][D][uart_debug:158]: <<< "\x05\x182\x00 :"
[14:16:00][D][uart_debug:158]: <<< "\x04\x182\x00 ;"
[14:16:02][D][uart_debug:158]: <<< "\x04\x182\x00 ;"
```

Next steps is to run add the c code in and update the esphome config to talk to the actual unit.

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

jourdant, 2023-09-03:
I've got it connected up to the HVAC now. I'm having power issues where the 12v line drops to ~9v when I plug it in (even without the panel also connected)... So for now doing testing with usb plugged in to help with the power supply issues. Open to any ideas here.

Regardless though, I've got messages coming back that match the format in the [protocol.md](https://github.com/JanM321/esphome-lg-controller/blob/58857923281c16042d5d8d1fb410b4346fd2f46a/protocol.md) file!

Here's an extract if anyone is interested in what I'm seeing from my unit:

### 0xC8 example:
```[D][uart_debug:196]: <<< 0b11001000 (0xC8) 0b00010000 (0x10) 0b00000000 (0x00) 0b00000000 (0x00) 0b01000000 (0x40) 0b00000000 (0x00) 0b00100101 (0x25) 0b00001101 (0x0D) 0b00000000 (0x00) 0b00000000 (0x00) 0b00000000 (0x00) 0b00000011 (0x03) 0b00011000 (0x18)```

### 0xCC example:
```[D][uart_debug:196]: <<< 0b11001100 (0xCC) 0b00101101 (0x2D) 0b00001001 (0x09) 0b00000000 (0x00) 0b00000000 (0x00) 0b00000000 (0x00) 0b00000000 (0x00) 0b00000000 (0x00) 0b00000000 (0x00) 0b00100000 (0x20) 0b00000000 (0x00) 0b00000000 (0x00) 0b01110111 (0x77)```
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
JanM321, 2023-11-21:
> I've looked up the installer manual for your unit and you're in luck - your unit is actually compatible with the PI-485 communications board. Essentially for older outdoor units that don't have Central Control pins onboard, you can use the PI-485 board to present an RS485 LGAP interface for your unit. See here: https://www.usermanuals.au/lg/mu2r17ul0/manual?p=22 page 22.

Thanks for checking, but I think those units are the bigger ones that support at least 3 indoor units. My MU2R17 is the 16k version and the MU2R15 is 14k. Starting with the MU3R19 (18k) the outdoor units get a bit more advanced. I think the duo-split units are a bit of an awkward combination of single-split and multi-split.

jourdant, 2023-11-22:
> Thanks for checking, but I think those units are the bigger ones that support at least 3 indoor units. My MU2R17 is the 16k version and the MU2R15 is 14k. Starting with the MU3R19 (18k) the outdoor units get a bit more advanced. I think the duo-split units are a bit of an awkward combination of single-split and multi-split.

After looking on the model number, I see what you're talking about now. That's really unfortunate!

I've spent a bit more time expanding on the LGAP protocol here: https://github.com/jourdant/esphome-lgap/blob/main/protocol.md, I've used the same format you have in this repo too. It's a good way to lay things out for seeing the relevant bytes etc.

JanM321, 2023-11-22:
Great. There are still some unknown bits in the indoor unit messages, so maybe this will help with that too.

JanM321, 2024-02-03:
I'll close this issue because you've moved on to the LGAP project :) The hardware-tiny PCB also addresses some of the same issues. Feel free to reopen or file a new issue if you want to get back to this.

Gunner251192, 2024-02-26:
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

Hi All, Does someone have one assembled piece at spare which I can take over? I live in NL.
I tried to order them trough JLPC assembled but with your supplied files it is currently not possible since:

<!--StartFragment-->
C3 | 22uF | CP_Elec_4x5.8 | EEEFPC220UARC40175822uF 16V 160mA@100kHz 850mΩ@100kHz ±20% SMD,D4xL5.8mm Aluminum Electrolytic Capacitors - SMD ROHS | 5 |   | Extended | $0.00 | 5 shortfall
-- | -- | -- | -- | -- | -- | -- | -- | --
<!--EndFragment-->

The 22uF capacitors are not available at JLPCB, I don't know with wat to replace them, I also don't need 5 boards to be honest.

belly-89, 2024-02-28:
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

Hi, Yes i have a spare PCB, had to order 5 pieces at once and only needed two. So i can send you one. Send me a message to make arrangement.

Thanks for mentioning me @JanM321

Gunner251192, 2024-02-28:
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

Hi [belly-89](https://github.com/belly-89),

Please let me know how I can reach out to you.

Regards Nick.

belly-89, 2024-02-28:
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

Are you on tweakers.net? You can send me an PM there, username belly89

belly-89, 2024-04-03:
> Hey @belly-89 Do you happen to still have one of these PCBs laying around? I would like to buy one of them if you still do. Thanks!

No sorry, I don't have any PCB boards left.

jourdant, 2024-04-26:
@JanM321 you've made so much awesome progress on your integration! I've got my LGAP protocol fully working now as an external component presenting a climate interface - using off the shelf parts. Feel free to check it out sometime, interested in any feedback, especially if you have any suspicions on the protocol, there's still a few bytes I haven't mapped that may look familiar to you 🙂 https://github.com/jourdant/esphome-lgap

JanM321, 2024-04-28:
> I've got my LGAP protocol fully working now as an external component presenting a climate interface - using off the shelf parts.

Nice work. I like the HA screenshot showing multiple climate entities :)

> especially if you have any suspicions on the protocol, there's still a few bytes I haven't mapped that may look familiar to you

Nothing stands out. It might be worth exposing values to HA with a temporary sensor so you can see if there’s a pattern. Pipe temperature values in particular should stand out that way - they might use a similar encoding to the one I reverse engineered from the indoor unit controllers.

jbutlerdev, 2024-08-23:
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

Is it possible to get an updated bom? It seems like some parts are no longer available and I'm not sure what substitute to pick.

reconfigrr, 2025-01-05:
I am also hoping for an updated BOM. Im not an electrical engineer, but I have attempted to find some substitutes for the parts no longer available. Hoping someone might be able to confirm if these are ok.

VZH100M1CTR-0405 replacing EEE-FC1C100AR
0402B332K500NT replacing CL05B332KB5NNNC

Any help would be appreciated.

Closed 2024-02-03.

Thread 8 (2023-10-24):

Is there a file for the case ???

mshrem, 2023-10-24:
Hello first of all wow , amazing work.

A long time ago i decided to just drop the idea of controlling my AC because the inverter on my bedroom doesnt support the LG wifi module.

I am so pumped that you made this work, i already submitted the files to PCBway so they can build and assemble for me , however i was wondering if you happen to have the file for the accrylic case ? I kinda want to have everything made by them and i do not have any 3d printer .

Thanks

JanM321, 2023-10-24:
It's just an Adafruit 2359 Raspberry Pi case :) When I designed the PCB I was hoping it'd fit in a Pi case and this one works well.

It's also in the list of materials in hardware/materials.md

mshrem, 2023-10-24:
Thanks , i somehow missread that part.

One last thing i am a bit confused , do we have to power the unit itself with USB C and then connect to the HVAC ???? or does it use the power from the HVAC unit ?

JanM321, 2023-10-25:
> One last thing i am a bit confused , do we have to power the unit itself with USB C and then connect to the HVAC ???? or does it use the power from the HVAC unit ?

It's powered by the HVAC unit. You only need the USB port to flash the firmware on it the first time before connecting it to the AC.

mshrem, 2023-11-07:
So my pcbs are finally done but i think some of the orientation of the smds might be wrong .

Can someone take a look at this?

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

florianbrede-ayet, 2023-11-11:
Do you think the R values are incorrect?
Because otherwise resistors have no polarity, their orientation doesn't matter.

mshrem, 2023-11-16:
I am patienly waiting now for the order to be delivered , i went ahead flashed the firmware already on both of my esphomes, they are recognized in home assistant however i cannot add them in the ESPhome addon , i want to manage them in the esphome addon from home assistant for easier updates and such.

Ps i also orde your pcbs @florianbrede-ayet , they arrive soon

mshrem, 2023-11-17:
Finally everything is here altho i am encountering some issues.

I am attaching some pictures i know that the cables do not match , but i think i got it correctly , the espmodule doesnt even come on.

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

JanM321, 2023-11-17:
You need to switch the red and yellow wires on the PCB.

If you look at the colors of the wires *from the AC* it should be (from left to right on your picture) Red, Yellow, Black. Because the cable has different colors, it should be Yellow, Black, Red from left to right in the picture you posted.

I should have added some labels to the PCB about the colors, but my first goal was to get it working at all and back then I didn't expect this PCB to become so popular.

mshrem, 2023-11-18:
I have tried to swit many cables around and nothing happens , the esp light doesnt even come on , i can power the esp with a USB cable without problems and its recognized already in HA. Does the led on the ESPmodule is supposed to come on ?

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

Maybe the CN-REMO connector is not plugged into the board ?

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

JanM321, 2023-11-18:
> I have tried to swit many cables around and nothing happens , the esp light doesnt even come on , i can power the esp with a USB cable without problems and its recognized already in HA. Does the led on the ESPmodule is supposed to come on ?

The LED will be off when connected to the AC. It will only be on when connected to USB.

mshrem, 2023-11-18:
> >
>
> The LED will be off when connected to the AC. It will only be on when connected to USB.

Yup ,so stupid of me LOL i am kinda newbie to this esp world , just figured it out , works perfectly however commands take a few seconds to arrive to the unit when pressing them on the HA app is this the same behaviour for you ??

JanM321, 2023-11-18:
> Yup ,so stupid of me LOL i am kinda newbie to this esp world , just figured it out , works perfectly

Great!  🎉

> however commands take a few seconds to arrive to the unit when pressing them on the HA app is this the same behaviour for you ??

Yes that's expected. The LG communication protocol is slow (sending a complete message takes at least a second) and the controller internally "updates" every 6 seconds so there can be a delay of about 1-6 seconds depending on this 6 second cycle.

mshrem, 2023-11-18:
>
> Yes that's expected. The LG communication protocol is slow (sending a complete message takes at least a second) and the controller internally "updates" every 6 seconds so there can be a delay of about 1-7 seconds depending on this 6 second cycle.

Awesome job man , i cant thank you enough for all of the help , would be amazing if we can just use esphome addon on home assistant to just update the firmware , guess i need to learn more linux lol

JanM321, 2023-11-18:
> Awesome job man , i cant thank you enough for all of the help

No problem! It's great to see people all over the world using this. If you don't mind sharing, what kind of LG units do you have? I have a list of supported units in the README.

> would be amazing if we can just use esphome addon on home assistant to just update the firmware , guess i need to learn more linux lol

It may be possible to upload the firmware within Home Assistant and/or the ESPHome dashboard / add-on, but I don't really know this part of HA/ESPHome. When I was writing the software it was just easiest to use the command-line tools for testing. Maybe someone else reading this knows more about it.

mshrem, 2023-11-18:
> No problem! It's great to see people all over the world using this. If you don't mind sharing, what kind of LG units do you have? I have a list of supported units in the README.
>
Yup , i have the [ARNU18GSCR4](https://www.lgbusiness.it/climatizzazione/altri-codici/arnu18gscr4/) , which worked

Also works on the [ARNU36GSVA4](https://www.lgbusiness.es/climatizacion/multi-v/interiores/pared/pared-standard/arnu30gsva4-arnu36gsva4/)

Altho i broke the pin on one of the JSX connectors so i need to wait until monday to fix it since i am away for the weekend. I only have 1 working so far but tested on both devices and it worked.

> It may be possible to upload the firmware within Home Assistant and/or the ESPHome dashboard / add-on, but I don't really know this part of HA/ESPHome. When I was writing the software it was just easiest to use the command-line tools for testing. Maybe someone else reading this knows more about it.
>

Will be a plus but its not necessary so happy that i did not purchased the LG wifi module , plus the ARTCOOL Mirror doesnt even support it now i need to get some temperature sensors so i can automate the climate to always be on the perfect temperature , pumped about this.

JanM321, 2023-11-18:
Wow, the ARNU36GSVA4 is very powerful.

I added these to the README; maybe it will help someone with similar units.

Closed 2023-11-18.

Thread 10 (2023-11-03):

Bug In Temperature Reporting

florianbrede-ayet, 2023-11-03:
I noticed that my LG 4-Way-Cassette is always reporting the internal thermistor value in `C9`.
My Artcool Gallery behaves differently and responds with the value set by the controller.

This is a display issue though, the Cassette reacts correctly to whatever I set the *room temperature* in both `Controller` and `2TH` mode.
I guess it just keeps reporting its internal sensor to display it in PREMBT001 along with the controller sensor:

```
[23:06:26][D][lg-controller:371]: sending A8.12.00.08.40.00.12.8F.00.00.00.00.F6 (13)
[23:06:26][D][climate:380]: 'LG Schlafzimmer' - Sending state:
[23:06:26][D][climate:383]:   Mode: HEAT
[23:06:26][D][climate:388]:   Fan Mode: LOW
[23:06:26][D][climate:400]:   Swing Mode: OFF
[23:06:26][D][climate:403]:   Current Temperature: 17.50°C
[23:06:26][D][climate:409]:   Target Temperature: 17.00°C
[23:06:26][W][component:214]: Component <unknown> took a long time for an operation (0.54 s).
[23:06:26][W][component:215]: Components should block for at most 20-30ms.
[23:06:31][D][lg-controller:525]: update
[23:06:31][D][lg-controller:387]: received A8.12.00.08.40.00.12.8F.00.00.00.00.F6 (13)
[23:06:31][D][lg-controller:396]: verified send
[23:06:37][D][lg-controller:525]: update
[23:06:50][D][lg-controller:371]: sending A8.12.00.08.40.00.12.8F.00.00.00.00.F6 (13)
[23:06:50][W][component:214]: Component <unknown> took a long time for an operation (0.51 s).
[23:06:50][W][component:215]: Components should block for at most 20-30ms.
[23:06:55][D][lg-controller:525]: update
[23:06:55][D][lg-controller:387]: received A8.12.00.08.40.00.12.8F.00.00.00.00.F6 (13)
[23:06:55][D][lg-controller:396]: verified send
[23:07:01][D][lg-controller:525]: update
[23:07:13][D][lg-controller:582]: line busy, not sending yet
[23:07:19][D][lg-controller:525]: update
[23:07:19][D][lg-controller:582]: line busy, not sending yet
[23:07:25][D][lg-controller:525]: update
[23:07:25][D][lg-controller:387]: received C8.12.00.08.40.00.12.9A.00.00.00.00.9B (13)
[23:07:25][D][sensor:094]: 'Error Code': Sending state 0.00000  with 0 decimals of accuracy
[23:07:25][D][climate:380]: 'LG Schlafzimmer' - Sending state:
[23:07:25][D][climate:383]:   Mode: HEAT
[23:07:25][D][climate:388]:   Fan Mode: LOW
[23:07:25][D][climate:400]:   Swing Mode: OFF
[23:07:25][D][climate:403]:   Current Temperature: 23.00°C
[23:07:25][D][climate:409]:   Target Temperature: 17.00°C
[23:07:25][D][climate:380]: 'LG Schlafzimmer' - Sending state:
[23:07:25][D][climate:383]:   Mode: HEAT
[23:07:25][D][climate:388]:   Fan Mode: LOW
[23:07:26][D][climate:400]:   Swing Mode: OFF
[23:07:26][D][climate:403]:   Current Temperature: 23.00°C
[23:07:26][D][climate:409]:   Target Temperature: 17.00°C
[23:07:26][D][lg-controller:387]: received C8.12.00.08.40.00.12.9A.00.00.00.00.9B (13)
```

My fix for this is simple:
https://github.com/florianbrede-ayet/esphome-lg-controller/commit/b3d24963acff562d88caefb8056cbf7a7d67a934

Since I already added some functionality (hysteresis to fix the stupid LG behaviour in heating mode, setting installer messages in yaml, configurable setpoint thresholds), I wasn't sure if you're interested in a full PR.

JanM321, 2023-11-04:
Hm this sounds similar to the behavior the reporter in issue #4 was seeing. I actually wish my units would still report the internal temperature... I can land your fix.

> Since I already added some functionality (hysteresis to fix the stupid LG behaviour in heating mode, setting installer messages in yaml, configurable setpoint thresholds), I wasn't sure if you're interested in a full PR.

In case it helps: a few days ago I set installer setting 15 (heating temperature thresholds) to 4 (-0,5C/+0,5C). This makes my units work a lot more like how I want them to. In HA I use a filter sensor to average the temperature over 10 minutes to make it not turn on/off too aggressively.

florianbrede-ayet, 2023-11-04:
I need to experiment more with the overheating.
The artcool gallery is complete design failure, its layout makes it impossible to work well for heating.

It has an airflow loop from the side vents to the intake.
It would help to control them individually, but that seems to be unsupported.

When I set it to `4`, it won't heat anymore, because the ambient heat from the copper pipes is enough to heat the thermistor above 20°C at all times even with the fan running.

Do you know if the installer setting `(0: default for unit, 1: +4C/+6C, 2: +2C/+4C, 3: -1C/+1C, 4: -0.5C/+0.5C)` should apply to both unit and external controller thermistor?

Because by default, the device overheats by at least `6°C`.
As soon as I set it to external controller however, it stops at `>+2°C` without changing the setting above.

JanM321, 2023-11-04:
> Do you know if the installer setting `(0: default for unit, 1: +4C/+6C, 2: +2C/+4C, 3: -1C/+1C, 4: -0.5C/+0.5C)` should apply to both unit and external controller thermistor?
>
> Because by default, the device overheats by at least `6°C`. As soon as I set it to external controller however, it stops at `>+2°C` without changing the setting above.

My units behave the same in this regard with internal or external sensor. The default setting for wall units is +1/+3, so when I started using an external sensor I had to set it to 19C to make it turn on at 20C and off at 22C. Changing this installer setting to 3 or 4 fixed that; I can now set it to 20.5 or 21.

My wall units also aren't ideal for heating, especially for my unit that's near a corner. Fortunately the external sensor fixes most of that.

Closed 2023-11-04.

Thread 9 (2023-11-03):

Tiny PCB With Kicad Files

florianbrede-ayet, 2023-11-03:
Hi,
first thanks for the project and your effort, I've finally been able to reduce my "LG Artcool Gallery (Multi)" to bearable fan speeds, which helps a lot.
I still have different issues with my MU3R19 setup, because in heating it doesn't modulate correctly.
But unfortunately, no error is ever reported, so I have to continue looking for an LGMV dongle.

Anyway, the Artcool Gallery is tight on space and the parts of your PCB are quite hard to source and rather expensive, I designed a tiny pcb with an ESP32 DevKit footprint (around $8 per piece assembled at jlcpcb):
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

The files are currently in my fork, but if you're interested I could create a PR:
https://github.com/florianbrede-ayet/esphome-lg-controller/tree/main/hardware-tiny

JanM321, 2023-11-04:
This is really nice.

This was my first PCB so I tried to follow the project I based the hardware on as much as possible to not break something, but it's good to have an alternative design that works. I thought the TI LIN transceiver was the only one that didn't have the timeout feature but you found another one :)

If you could do a PR for the hardware-tiny directory, that'd work. I could also link to your fork in the README file - let me know which option you prefer.

I never expected this project to get this much attention :) I'm now thinking about rewriting the software a little to make it easier to send/receive other message types.

mshrem, 2023-11-07:
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

Ohhhhh wow this is awesome i wish i had seen this before i placed the order with pcbway. I also have some Artcool Gallery so this will help me.
I think they soldered some [parts incorrectly ](https://github.com/JanM321/esphome-lg-controller/issues/8#issuecomment-1798005828) but i am waiting on verification otherwise if they did i will kindly ask them to change them for this layout.

JanM321, 2023-11-07:
@florianbrede-ayet did you want to create a pull request for this? I think this could help a lot of people.

florianbrede-ayet, 2023-11-07:
@JanM321 just did, it got lost with my fork reset.

JanM321, 2023-11-08:
Thanks! I merged the PR and added a comment to the README about this.

Closed 2023-11-08.

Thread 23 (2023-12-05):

hardware-tiny lot of extended lib type component

echoTheo, 2023-12-05:
This is not a bug but a possible improvement.

I try to order the tiny hardware PCB on JLCBCB but a lot of enxended library components are used.

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

An extra fee is apply on each extended lib type component.

@florianbrede-ayet, could it be possible to use a maximum of basic lib type component to reduce the cost of the PCB ?

bleughb, 2023-12-05:
Most of them should be changeable to BASIC components
 As long as the values and tolerances are the same, go find a cheaper / BASIC version
it's easy enough to filter the JLCPCB choice menus, probably take you half a day to get them all changed over, create a new BOM and post it here for everyone to benefit

If footprint is different, just change it on the PCB layout.
OR, research and find ones with same footprint that are BASIC and cheaper
consider soldering the pinheaders yourself maybe? those are Through Hole so only available on extended

Component research and choice is probably the hardest and certainly the most tedious aspect of PCB design!

florianbrede-ayet, 2023-12-05:
@echoTheo some of the extended parts are actually *preferred extended parts* you're not being charged for.

Some others are non-replaceable (regulator & transceiver).

What is replaceable are the capacitors, but I had bad luck with cheap caps (multiple boards I had assembled in 2018-2020 failed already with blown caps), so I chose TDK & Panasonic instead.

As @bleughb said, you can just update the `bom.csv` with cheaper basic parts matching the footprint.

For the diode, JLCPCB didn't have a basic part available with more than 150mA continuous current.
While this is debatable, I wanted to play safe since the controller can exceed 200mA.

JanM321, 2024-02-03:
Closing because this has been answered.

Closed 2024-02-03.

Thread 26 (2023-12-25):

Case for hardware-tiny

kchen, 2023-12-25:
Hi,

I'm planning to add hardware-tiny to my LG mini-split units, and @florianbrede-ayet or others, I'm wondering whether you have any recommendations for cases. I did see that #8 mentions the case for the non-tiny hardware, and I'll probably try that if I don't find anything better.

Also, are there any known concerns about heat? Is there any known problem if I put it in a case without a few air holes? Or are there any issues if I just attach the hardware to the wall inside the mini-split?

Thanks!

kchen, 2024-01-10:
I just saw in #9 that no case is used, and it's just placed inside the indoor unit, so it seems like heat is not a concern.

Since I filed the ticket, I did end up using the Adafruit 2359 Raspberry Pi that Jan mentioned in #8, which seems to work fine. I run the wire to the outside of the unit, and stick the case to the wall right outside the unit.

Also, if anyone is looking for relevant wiring, I ended up using https://www.amazon.com/dp/B0BW9TQTBK . I had some trouble finding wire with a connector on both ends, and eventually found this one.

kchen, 2024-01-26:
I no longer recommend the wiring above. On some of my units, it works fine, but on others, the connection is loose, and in one case, it won't stay attached to the mini-split unit wiring at all. I think this might not be a problem with the product itself, but rather possibly general incompatibility between the JST XH connector and the receptacle on the LG cable.

I've instead acquired the official LG thermostat cable, and then spliced it with wiring with the JST XH connector, and so far, that seems to be working better.

Closed 2024-01-10.

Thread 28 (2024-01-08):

Low-Medium and Medium-High fan speeds not supported

kchen, 2024-01-08:
My indoor unit supports the Low-Medium and Medium-High fan speeds (via the physical remote), but not via esphome-lg-controller. Surprisingly, changing to these fan modes is also not supported in the LG ThinQ Android app, although the "SmartThinQ LGE Sensors" Home Assistant integration does support them. (I think my indoor unit may also support fan mode 7 "power", although I'm not certain.)

(I see that lg-controller.h already has some support for these fan modes. I also see that the Climate component of ESPHome supports custom fan modes, which I assume are the relevant thing to use to implement this. I haven't dug through all the code to ensure that everything works the way I think it does, though.)

JanM321, 2024-01-08:
The protocol does have support for Low-Medium and Medium-High fan modes, but my units don't recognize these values if I send them manually. You could try this with your indoor unit (see protocol.md) but I expect it won't work, if your unit is similar to mine.

When using these fan modes with the wireless remote or ThinQ, the wired controller will just receive Medium, IIRC. At least the AC unit is smart enough to not reset it to the actual Medium fan mode later if the controller doesn't change it.

It's really unfortunate that the Wifi controller and wired controller have a different set of features.

florianbrede-ayet, 2024-01-16:
Some devices support customizable fan speeds through *Installer Setting 3*.
I played around with that a little and it was really nice, however the setting is persisting power cycles.
So every change will likely wear the controller's EEPROM / Flash.

Anyway, if *Installer Setting 3* is supported, you might find a speed configuration that satisfies your needs even with just 3 fan speeds available.

kchen, 2024-02-18:
I finally got around to testing this, and can confirm what you said. It appears that when I set the fan speed to 5 or 6, the change is ignored. In addition, it looks like the capabilities message also does not report supporting low-medium or medium-high.

I noticed that the capabilities message does report that my unit supports fan speed 7. While performing this testing, I had my unit on fan only mode, but when I set the fan speed to power, the unit automatically set itself to cooling mode and 64 F, so it appears that power is not a normal fan speed, so we probably wouldn't want it as one. (I've seen power mode in heat mode before using either the physical remote or the LG app, but similarly, I don't think it would be desirable as a normal fan option.)

JanM321, 2024-02-18:
> I noticed that the capabilities message does report that my unit supports fan speed 7. While performing this testing, I had my unit on fan only mode, but when I set the fan speed to power, the unit automatically set itself to cooling mode and 64 F, so it appears that power is not a normal fan speed, so we probably wouldn't want it as one. (I've seen power mode in heat mode before using either the physical remote or the LG app, but similarly, I don't think it would be desirable as a normal fan option.)

That's good to know, I haven't tried this option yet. On the PREMTB100, 'Power Cooling' and 'Power Heating' are separate operation modes with fixed setpoint associated with it (30C / 86F for heating).

The ThinQ app has a Jet Mode switch. That would probably be the easiest way to implement this.

JanM321, 2024-02-18:
I did some testing and my units only support the Power Fan option in Cooling mode. I can turn on the Jet option in the ThinQ app in heating mode, but the unit just resets it after a few seconds and also sends 'medium' to the wired controller. It looks like having a wired controller connected prevents my units from using this in heating mode.

Maybe I'll get back to this in the summer. I also want to add a toggle for the 'auto dry' / 'auto clean' option but that's also easier to test when the units are in cooling mode.

landrysik, 2024-03-06:
> It looks like having a wired controller connected prevents my units from using this in heating mode.

Hi, thanks for all the work. I just started using this project and noticed that with the wired controller connected I can't set the Jet mode (at least while heating) on my AC (LG Standard plus, PC12SK). I would understand if it is not implemented in the code but how is it possible that I can't set this even with IR remote or LG ThinQ app? AC completely ignores the button press on IR remote or ThinQ app...

Do you think this can be fixed somehow? I used the Jet mode quite frequently as the high fan speed nicely mixes air around the whole room when nobody is home (so the noise is not an issue)
Thanks!

Closed 2024-02-18.

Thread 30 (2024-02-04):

Not an issue - TEsted working with LG Ducted

bleughb, 2024-02-04:
My LG Units are a 17.1kW Ducted
[B55AWYU3G5](https://www.manualslib.com/products/Lg-B55awyu3g5a-11273601.html) - Indoor Unit
and
[ABUW55G7SB0](https://www.lg.com/au/support/product/lg-B55AWYN7G5) - Outdoor UNit

and I have installed myself a PREMTB100 controller.
My PCB is sitting on a jumper wire to the PREMTB100 controller

Everything seems to be working just fine right now!

I've disabled the LG Wifi dongle now as it seems to make the integration a little flakey - which is expected as the LG dongle is itself a little flakey, to the point where we couldn't rely upon it to use it from our mobiles.
Now we have your code installed, it's rock solid :-)
Thankyou!
here's hoping I get time to help out

JanM321, 2024-02-05:
Thanks! I added it to the list. Good to hear it works with ducted units too.

Are there things you still use the PREMTB100 for because they're not supported by the controller? Maybe zone control?

bleughb, 2024-02-05:
> Thanks! I added it to the list. Good to hear it works with ducted units too.
>
> Are there things you still use the PREMTB100 for because they're not supported by the controller? Maybe zone control

We use the controller for a quick easy override / kids can control it.
still haven't fully adopted Home Assistant everywhere,
plus it looks good on the wall.

I'm not using the zone control - which is supported, but plan to hook up our 3 zones and add more in the future.

rajkundu, 2024-07-20:
I'm not sure if this is the right place to ask, but I have an LG air conditioning system that it is built into my apartment, almost like a "central" system (I believe it is a "ducted" system just like @bleughb's). Unfortunately, this means that I have no idea what my indoor or outdoor units are; all I know is that my thermostat is an LG PREMTB10U, and it has 3 wires - power, ground, and signal.

My understanding is that the usual use case of this community is with an LG wall-mount unit, connected to an outdoor unit, which supports a device like the PREMTB10U via the CN-REMO connection. However, most people do not have such a thermostat/remote installed by default, so they open up the indoor/wall unit and connect this device instead.

So, I am hoping that I should be able to replace my PREMTB10U with this project's PCB, pretty much exactly as it seems @bleughb has done. Does that sound right - that I could simply connect the same 3 wires from my PREMTB10U (power, ground, signal) to this project's PCB, and it would work?

I know you can't guarantee anything, of course, but what do you think? Anyway, thank you so, so much @JanM321 for your _**tremendous**_ work on this project!!!

JanM321, 2024-07-20:
> I am hoping that I should be able to replace my PREMTB10U with this project's PCB, pretty much exactly as it seems @bleughb has done. Does that sound right - that I could simply connect the same 3 wires from my PREMTB10U (power, ground, signal) to this project's PCB, and it would work? I know you can't guarantee anything, of course, but what do you think?

I expect that to work. For what it's worth, in issue #1 someone else replaced a PREMTB10U controller with the PCB.

Some of the LG controllers *also* support an older protocol for which there is an ESPHome implementation [here](https://github.com/Flameeyes/esphome-lg-pqrcuds0), but I hope my project will work. The hardware side is the same, it's just a completely different message format.

> Regardless, thank you so, so much @JanM321 for your _**tremendous**_ work on this project!!!

You're welcome! Please let me know if it works :)

rajkundu, 2025-06-01:
I can confirm that this setup works, with the PREMTB10U in master mode and the ESPHome controller in slave mode. **Thank you!**

Closed 2024-02-05.

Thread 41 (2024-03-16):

Half working with DC18RQ.NSK with opto-isolator hardware

robertklep, 2024-03-16:
I'm trying to get your controller code working using @AussieMakersGeek's [level shifter/opto isolator](https://github.com/AussieMakerGeek/LG_Aircon_MQTT_interface#connections) setup with a DC18RQ.NSK model.

It seems to be working _somewhat_, in that I see certain sensors being updated in HA (for instance, the outdoor unit and preheat states). Also, I can change the airflow sensor in HA and the AC picks it up.

However, a lot of things don't work: reading/setting the mode, reading/setting the target temperature, etc.

The ESP32 is logging a lot of errors:
```
[12:09:27][D][lg-controller:1305]: update
[12:09:27][E][lg-controller:1324]: did not receive message we just sent
[12:09:33][D][lg-controller:1305]: update
[12:09:39][D][lg-controller:1305]: update
[12:09:45][D][lg-controller:1305]: update
[12:09:45][E][lg-controller:1346]: discarding incomplete data A9
[12:09:51][D][lg-controller:1305]: update
[12:09:52][D][lg-controller:861]: sending AA.00.00.00.00.00.00.01.00.02.F1.21.EA (13)
[12:09:57][D][lg-controller:1305]: update
[12:09:57][D][lg-controller:905]: received AA.C8.30.00.00.40.00.16.00.00.00.00.00 (13)
[12:09:57][E][lg-controller:915]: invalid checksum AA.C8.30.00.00.40.00.16.00.00.00.00.00 (13)
[12:09:57][E][lg-controller:1324]: did not receive message we just sent
```

I'm not sure where to look. I'm perfectly willing to accept that the hardware setup that I'm using might be causing these issues, but it seems strange that some TX/RX's work (consistently) and others don't, which suggests that it might be caused by my AC perhaps using a different protocol version (if that makes sense).

JanM321, 2024-03-16:
> which suggests that it might be caused by my AC perhaps using a different protocol version (if that makes sense).

That's unlikely. Your unit is very similar to other units that work fine with this controller.

In the log output you posted, the controller is trying to send an AA message (which controls the airflow up/down setting among other things), but there might be a conflict with the AC sending a C8 message (status message) at the same time. In this case the controller will keep sending this message until it succeeds.

Did you change the RX/TX pin numbers? In that case make sure you also change `RxPin` in the header file.

JanM321, 2024-03-16:
If you can pastebin the full log output (including controller startup + a few minutes after that) I can take a look to see if there's anything unusual.

robertklep, 2024-03-16:
Thanks!

Here's the log: https://pastebin.com/Qk08fFkK

I did change the RX/TX pins but edited the header file accordingly.

A few things that might be relevant:
* the original schematic is showing two 270Ω resistors, I only had 220Ω. Probably not an issue though?
* the original schematic is powering the level shifter from the 5V pin from an Arduino, but since I'm using an ESP32 I assumed I need to drive it from 3.3V. However, I didn't change the resistor to the optocoupler, perhaps that's problematic? I do see the LED flash whenever a message is being sent.

JanM321, 2024-03-16:
> Here's the log: https://pastebin.com/Qk08fFkK

14:09:45: the controller sends its initial message and reads it back on the bus. The AC doesn't respond to this for a while (this means messages aren't received by the AC or are corrupted somewhere)
14:13:58: finally the unit responds by sending all its settings (part of initialization)
14:14:22: controller tries to send an AA message (it always does this after initialization) but it never reads it back on the bus, so it gets stuck trying to send this. The controller is still receiving messages from the AC occasionally.

This explains what you're seeing. The controller is stuck trying to send an AA message (this has the airflow up/down setting but not the other settings) because it fails to read it back on the bus. The controller is still processing status messages from the AC so sensors are updating.

It's very close to working (you can both send and receive messages sometimes) but communication is buggy because something isn't quite right.

Are you using a 12V / 3.3V level shifter? It could be the resistor on the ESP32 side maybe, but I'm not as familiar with this schematic.

robertklep, 2024-03-16:
The level shifter I'm using should support 3.3V on the low side and 12V on the high side, but I don't necessarily trust it. I'll see if I can source a proper 12/3.3V level shifter just to rule out that this is the cause.

I'll try and see if I can the resistor on the ESP32 side to match the lower voltage.

Thanks for now, I'll update this issue when I find out more.

robertklep, 2024-03-20:
I took the easy way out and bought two of your controllers, courtesy of @belly-89 😅

I do have an additional aircon unit (one we don't often use) that I might try when I receive the other level shifters, but I'll close the issue for now. Thanks again 😊

robertklep, 2024-03-20:
FWIW, you can add the DC18RQ.NSK to the list of supported devices. I didn't have an ESP32-DevKit module available so I hooked it up to an ESP32-C3 SuperMini board, which works fine (I'll clean up the wiring at a later date 😁).

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

JanM321, 2024-03-22:
> FWIW, you can add the DC18RQ.NSK to the list of supported devices. I didn't have an ESP32-DevKit module available so I hooked it up to an ESP32-C3 SuperMini board, which works fine (I'll clean up the wiring at a later date 😁).

Done! I'm glad it works now with the PCB.

belly-89, 2024-03-22:
> FWIW, you can add the DC18RQ.NSK to the list of supported devices. I didn't have an ESP32-DevKit module available so I hooked it up to an ESP32-C3 SuperMini board, which works fine (I'll clean up the wiring at a later date 😁).
>
> ![F1B7FAA2-C541-471D-9600-76C169510A93](https://private-user-images.githubusercontent.com/1190916/314492419-0dc14952-0014-43d6-b332-f0a7d3d5e10d.jpeg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)

Nice to see it working! 🙂

Closed 2024-03-20.

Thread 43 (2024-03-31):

Quick temperature sensor choice

pieca2, 2024-03-31:
Hi,

it isn't a real issue, but I'm using an Aquara temperature sensor and it is too slow to properly control my HVAC quickly. it could wait 10 min to report a change from 1°C...

What temperature sensor are you recommending for a fast response when temperature is changing and get a proper control ?

Thanks for your help

landrysik, 2024-03-31:
I think the best temperature sensor for this purpose is LYWSD03MMC or similar BLE thermometer supported with firmware from pvvx. You can directly receive the BLE signal using the same ESP32. It updates every few seconds and have 0.0X °C resolution

JanM321, 2024-04-01:
I use the Xiaomi Mi 2 sensors with pvvx firmware. You can flash the firmware here: https://pvvx.github.io/ATC_MiThermometer/TelinkMiFlasher.html

I use this with an M5Stack Atom Lite. You can easily set these up as bluetooth proxy: https://esphome.io/projects/?type=bluetooth

landrysik, 2024-04-03:
With some code modification (haven't tried it yet) it would be possible to receive the BLE transmissions by the ESP32 and directly use this value. Use this code instad BT proxy.
https://esphome.io/components/sensor/xiaomi_ble.html#lywsd03mmc
As an advantage this will work independently on HA server. You could install this in your friend's AC even if they don't use HA at all

JanM321, 2024-04-03:
> With some code modification (haven't tried it yet) it would be possible to receive the BLE transmissions by the ESP32 and directly use this value.

True, I've thought about doing this or enabling the bluetooth proxy feature, but I like the flexibility of a HA sensor (I actually use a template sensor). The ESP32 also uses more power when BLE is enabled. That's probably okay but when I started this project I wanted to play it safe and keep it to a minimum.

JanM321, 2024-04-08:
I added a link to this issue to the Tips section in the README.

I think we can close this but anyone feel free to add additional comments.

pieca2, 2024-04-08:
**Issue solved** using an ESP32 mini D1 with a Dallas DS18B20 sensor directly soldered on the board with a resistor & Esp home.
This DIY sensor report temperature each 30 seconds with a great precision and from know my HVAC temperature is really stable and well regulated !!!!

rajkundu, 2025-04-02:
I'm so sorry if this is either obvious or already answered elsewhere, but I couldn't seem to find the answer: Is there any way to use the built-in LG temperature sensor instead of a custom sensor on HA? Is it okay to have an empty or invalid value for `temperature_sensor_entity_id` in template.yaml?

My current goal is to try and use the ESP controller in slave mode while preserving my original, wall-mounted PREMTB10U in master mode.

JanM321, 2025-04-02:
> I'm so sorry if this is either obvious or already answered elsewhere, but I couldn't seem to find the answer: Is there any way to use the built-in LG temperature sensor instead of a custom sensor on HA? Is it okay to have an empty or invalid value for `temperature_sensor_entity_id` in template.yaml?

I'm not 100% sure but I *think* you can use an invalid sensor id such as `sensor.invalid`...

> My current goal is to try and use the ESP controller in slave mode while preserving my original, wall-mounted PREMTB10U in master mode.

In slave mode the temperature sensor isn't used, the unit will get the temperature from either the unit itself or the master controller.

rajkundu, 2025-04-02:
Thank you very much! I will try using `sensor.invalid` for now and proceed from there.

rnivz, 2025-04-20:
Hi,

It would be great if it were possible to use the Xiaomi LYWSD03MMC (pvvx) with the ESP32 board.
Has anyone already implemented this or a guide with the necessary steps? Including the required adjustments to the YAML file?

JanM321, 2025-04-21:
> It would be great if it were possible to use the Xiaomi LYWSD03MMC (pvvx) with the ESP32 board. Has anyone already implemented this or a guide with the necessary steps? Including the required adjustments to the YAML file?

Someone added support for using the ESP32 as a bluetooth proxy (I haven't tested this myself). For this you need to uncomment [these lines](https://github.com/JanM321/esphome-lg-controller/blob/89ce8bd4a95a039eef131e744925303344950f85/esphome/base.yaml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). Changing from arduino to esp-idf might not be possible with flashing over wifi but I'm not sure about that. This would let the ESP32 forward the pvvx messages to Home Assistant.

rajkundu, 2025-06-01:
> Thank you very much! I will try using `sensor.invalid` for now and proceed from there.

I can confirm that this works - I finally set everything up today! Thank you so much, @JanM321, for this phenomenal repo. It has made it unbelievably easy to accomplish a dream that I have had since moving into my apartment, both on a hardware and software level. Had I known it was this easy, I would have done it months earlier. Thank you!!

JanM321, 2025-06-01:
Thanks to @leoshusar (PR #108) the temperature sensor is now optional, so if you don't use your own sensor you can comment it out or delete it in the YAML file.

Closed 2024-04-08.

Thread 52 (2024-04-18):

LG Controller as External Component

rrooggiieerr, 2024-04-18:
Since Custom Components are deprecated and will be removed from ESPHome in a future release I put some time in refactoring the library to a custom component.

https://esphome.io/custom/custom_component
https://esphome.io/components/external_components

Before I submit a pull request I'd like you to take a look at what I did:
https://github.com/rrooggiieerr/esphome-lg-controller

The following minimal yaml should give you a working HVAC module.
```
external_components:
  - source:
      type: local
      path: components
    components: [lg_controller]

uart:
  tx_pin: GPIO25
  rx_pin: GPIO26
  baud_rate: 104

lg_controller:

climate:
  - platform: lg_controller
    name: Heatpump
```

The External Component is not dependant on aditional components, however they can be added if needed:
```
sensor:
  - platform: lg_controller
    name: Error Code
    entity_id: error_code
  - platform: lg_controller
    name: Pipe Temperature In
    entity_id: pipe_temperature_in
    entity_category: diagnostic
  - platform: lg_controller
    name: Pipe Temperature Mid
    entity_id: pipe_temperature_mid
    entity_category: diagnostic
  - platform: lg_controller
    name: Pipe Temperature Out
    entity_id: pipe_temperature_out
    entity_category: diagnostic

binary_sensor:
  - platform: lg_controller
    name: Defrost
    entity_id: defrost
  - platform: lg_controller
    name: Preheat
    entity_id: preheat
  - platform: lg_controller
    name: Outdoor Unit
    entity_id: outdoor

switch:
  - platform: lg_controller
    name: Air Purifier
    entity_id: air_purifier
  - platform: lg_controller
    name: Internal Thermistor
    entity_id: internal_thermistor

select:
  - platform: lg_controller
    name: Airflow 1 Up/Down
    entity_id: vane_position_1
  - platform: lg_controller
    name: Airflow 2 Up/Down
    entity_id: vane_position_2
  - platform: lg_controller
    name: Airflow 3 Up/Down
    entity_id: vane_position_3
  - platform: lg_controller
    name: Airflow 4 Up/Down
    entity_id: vane_position_4
  - platform: lg_controller
    name: Over Heating # Installer setting 15.
    entity_id: overheating

number:
  - platform: lg_controller
    entity_id: fan_speed_slow
    name: "Fan Speed Slow"
    icon: mdi:fan-chevron-down
    mode: box
  - platform: lg_controller
    entity_id: fan_speed_low
    name: "Fan Speed Low"
    icon: mdi:fan-speed-1
    mode: box
  - platform: lg_controller
    entity_id: fan_speed_medium
    name: "Fan Speed Medium"
    icon: mdi:fan-speed-2
    mode: box
  - platform: lg_controller
    entity_id: fan_speed_high
    name: "Fan Speed High"
    id: fan_speed_high
    icon: mdi:fan-speed-3
    mode: box
  - platform: lg_controller
    entity_id: sleep_timer
    name: "Sleep Timer"
    icon: mdi:timer-outline
    mode: box
```

JanM321, 2024-04-21:
Thanks for looking into this!

This should be done at some point, but I want to play with this a bit more myself before taking a large refactoring. I wonder if there's a more incremental way to move away from custom components but I haven't looked into it yet.

JanM321, 2024-04-27:
I rewrote the code as an external component in 942f2f61b7f4654a65bd2fbd1bd9f1cb27b0ecc5.

Thanks for reporting the deprecation issue. I'm glad I was able to fix this without having to reorganize the code too much, but at some point it probably makes sense to split up `lg-controller.h` a bit more.

Closed 2024-04-27.

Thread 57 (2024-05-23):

LG H12AL (ASNW126MMS6)

DavidAntonin, 2024-05-23:
Hi, I have finally created my own PCB for the ESP32-S2 and have had partial success with my LG Prestige split air conditioner. I can switch modes, temperature, fan speed and set horizontal and vertical oscillation. I miss the ability to set a specific air direction - I can set 6 vertical positions and 5 horizontal from the remote.
Occasionally I get invalid checksum for a reason unknown to me (e.g. once every 30 minutes).
I am sending the log below.

Since my unit does not have power metering, I would like to use the PZEM-004T . The problem is that it also communicates via UART. ESPHome allows to use several UARTs with their own id. In the YAML file it even says "id: ac_serial". However, in the source files this id is not used and so when trying to add another UART with a different id, the program cannot be compiled. Would it be possible to modify the source code to use id: ac_serial? Thank you

`[14:02:23][C][wifi:421]:   Hostname: 'klima_lg_prestige'
[14:02:23][C][wifi:423]:   Signal strength: -31 dB ▂▄▆█
[14:02:23][C][wifi:427]:   Channel: 11
[14:02:23][C][wifi:428]:   Subnet: 255.255.255.0
[14:02:23][C][wifi:429]:   Gateway: 192.168.2.1
[14:02:23][C][wifi:430]:   DNS1: 192.168.2.1
[14:02:23][C][wifi:431]:   DNS2: 0.0.0.0
[14:02:23][C][logger:185]: Logger:
[14:02:23][C][logger:186]:   Level: DEBUG
[14:02:23][C][logger:188]:   Log Baud Rate: 115200
[14:02:23][C][logger:189]:   Hardware UART: USB_CDC
[14:02:23][C][uart.arduino_esp32:137]: UART Bus 0:
[14:02:23][C][uart.arduino_esp32:138]:   TX Pin: GPIO39
[14:02:23][C][uart.arduino_esp32:139]:   RX Pin: GPIO33
[14:02:23][C][uart.arduino_esp32:141]:   RX Buffer Size: 256
[14:02:23][C][uart.arduino_esp32:143]:   Baud Rate: 104 baud
[14:02:23][C][uart.arduino_esp32:144]:   Data Bits: 8
[14:02:23][C][uart.arduino_esp32:145]:   Parity: NONE
[14:02:23][C][uart.arduino_esp32:146]:   Stop bits: 1
[14:02:23][C][uptime.sensor:031]: Uptime Sensor 'Uptime'
[14:02:23][C][uptime.sensor:031]:   Device Class: 'duration'
[14:02:23][C][uptime.sensor:031]:   State Class: 'total_increasing'
[14:02:23][C][uptime.sensor:031]:   Unit of Measurement: 's'
[14:02:23][C][uptime.sensor:031]:   Accuracy Decimals: 0
[14:02:23][C][uptime.sensor:031]:   Icon: 'mdi:timer-outline'
[14:02:23][C][captive_portal:088]: Captive Portal:
[14:02:23][C][mdns:115]: mDNS:
[14:02:23][C][mdns:116]:   Hostname: klima_lg_prestige
[14:02:23][C][ota:096]: Over-The-Air Updates:
[14:02:23][C][ota:097]:   Address: klima_lg_prestige.local:3232
[14:02:23][C][ota:100]:   Using Password.
[14:02:23][C][ota:103]:   OTA version: 2.
[14:02:23][C][api:139]: API Server:
[14:02:23][C][api:140]:   Address: klima_lg_prestige.local:6053
[14:02:23][C][api:142]:   Using noise encryption: YES
[14:02:23][C][wifi_signal.sensor:009]: WiFi Signal 'WiFi Signal'
[14:02:23][C][wifi_signal.sensor:009]:   Device Class: 'signal_strength'
[14:02:23][C][wifi_signal.sensor:009]:   State Class: 'measurement'
[14:02:23][C][wifi_signal.sensor:009]:   Unit of Measurement: 'dBm'
[14:02:23][C][wifi_signal.sensor:009]:   Accuracy Decimals: 0
[14:02:23][C][homeassistant.sensor:030]: Homeassistant Sensor 'temp_sensor'
[14:02:23][C][homeassistant.sensor:030]:   State Class: ''
[14:02:23][C][homeassistant.sensor:030]:   Unit of Measurement: ''
[14:02:23][C][homeassistant.sensor:030]:   Accuracy Decimals: 1
[14:02:23][C][homeassistant.sensor:031]:   Entity ID: 'sensor.my_sensor'
[14:02:27][D][lg-controller:1351]: update
[14:02:27][E][lg-controller:1392]: discarding incomplete data 00.00.00.07.1E.00.00.00.00.58 (10)
[14:02:33][D][lg-controller:1351]: update
[14:02:33][E][lg-controller:743]: unknown fan mode, using Medium
[14:02:33][D][lg-controller:846]: sending A8.21.00.00.00.00.07.14.40.00.80.00.F1 (13)
[14:02:33][W][component:237]: Component lg_controller.climate took a long time for an operation (509 ms).
[14:02:33][W][component:238]: Components should block for at most 30 ms.
[14:02:39][D][lg-controller:1351]: update
[14:02:45][D][lg-controller:1351]: update
[14:02:51][D][lg-controller:1351]: update
[14:02:51][D][lg-controller:943]: received A8.21.00.00.00.00.07.14.40.00.80.00.F1 (13)
[14:02:51][D][lg-controller:959]: verified send
[14:02:51][D][lg-controller:943]: received C8.20.00.00.00.00.07.1E.00.00.40.00.18 (13)
[14:02:51][D][binary_sensor:036]: 'Defrost': Sending state OFF
[14:02:51][D][binary_sensor:036]: 'Preheat': Sending state OFF
[14:02:51][D][sensor:094]: 'Error Code': Sending state 0.00000  with 0 decimals of accuracy
[14:02:51][D][binary_sensor:036]: 'Outdoor Unit': Sending state OFF
[14:02:51][D][binary_sensor:036]: 'Auto Dry Active': Sending state OFF
[14:02:51][D][climate:396]: 'Klima LG Prestige' - Sending state:
[14:02:51][D][climate:399]:   Mode: OFF
[14:02:51][D][climate:416]:   Swing Mode: OFF
[14:02:51][D][climate:419]:   Current Temperature: 25.00°C
[14:02:51][D][climate:425]:   Target Temperature: 22.00°C
[14:02:51][D][switch:055]: 'Air Purifier': Sending state OFF
[14:02:51][D][climate:396]: 'Klima LG Prestige' - Sending state:
[14:02:51][D][climate:399]:   Mode: OFF
[14:02:51][D][climate:404]:   Fan Mode: MEDIUM
[14:02:51][D][climate:416]:   Swing Mode: OFF
[14:02:51][D][climate:419]:   Current Temperature: 25.00°C
[14:02:51][D][climate:425]:   Target Temperature: 22.00°C
[14:02:51][D][lg-controller:943]: received C8.20.00.00.00.00.07.1E.00.00.40.00.18 (13)
[14:02:51][D][sensor:094]: 'Error Code': Sending state 0.00000  with 0 decimals of accuracy
[14:02:51][D][lg-controller:1074]: ignoring because pending change
[14:02:51][D][lg-controller:943]: received C8.20.00.00.00.00.07.1E.00.00.40.00.10 (13)
[14:02:51][E][lg-controller:953]: invalid checksum C8.20.00.00.00.00.07.1E.00.00.40.00.10 (13)
[14:02:51][D][lg-controller:943]: received C9.C4.EA.1F.80.30.00.C0.02.00.00.00.5D (13)
[14:02:51][D][lg-controller:943]: received C9.C4.EA.1F.80.30.00.C0.02.00.00.00.5D (13)
[14:02:51][D][lg-controller:943]: received CA.E0.00.00.00.00.00.00.00.02.F1.21.EB (13)
[14:02:51][D][select:015]: 'Airflow 1 Up/Down': Sending state 0 (Default) (index 0)
[14:02:51][D][select:015]: 'Airflow 2 Up/Down': Sending state 0 (Default) (index 0)
[14:02:51][D][select:015]: 'Airflow 3 Up/Down': Sending state 0 (Default) (index 0)
[14:02:51][D][select:015]: 'Airflow 4 Up/Down': Sending state 0 (Default) (index 0)
[14:02:51][D][switch:055]: 'Auto Dry': Sending state OFF
[14:02:51][D][number:012]: 'Fan Speed Slow': Sending state 0.000000
[14:02:51][D][number:012]: 'Fan Speed Low': Sending state 0.000000
[14:02:51][D][number:012]: 'Fan Speed Medium': Sending state 0.000000
[14:02:51][D][number:012]: 'Fan Speed High': Sending state 0.000000
[14:02:51][D][lg-controller:943]: received CA.E0.00.00.00.00.00.00.00.02.F1.21.EB (13)
[14:02:51][D][select:015]: 'Airflow 1 Up/Down': Sending state 0 (Default) (index 0)
[14:02:51][D][select:015]: 'Airflow 2 Up/Down': Sending state 0 (Default) (index 0)
[14:02:51][D][select:015]: 'Airflow 3 Up/Down': Sending state 0 (Default) (index 0)
[14:02:51][D][select:015]: 'Airflow 4 Up/Down': Sending state 0 (Default) (index 0)
[14:02:51][D][number:012]: 'Fan Speed Slow': Sending state 0.000000
[14:02:51][D][number:012]: 'Fan Speed Low': Sending state 0.000000
[14:02:51][D][number:012]: 'Fan Speed Medium': Sending state 0.000000
[14:02:51][D][number:012]: 'Fan Speed High': Sending state 0.000000
[14:02:51][D][lg-controller:943]: received CB.00.00.FF.FF.75.00.00.00.00.00.00.6B (13)
[14:02:51][D][select:015]: 'Over Heating': Sending state 0 (Default) (index 0)
[14:02:51][D][sensor:094]: 'Pipe Temperature Mid': Sending state 24.00000 °C with 0 decimals of accuracy
[14:02:51][D][lg-controller:943]: received CB.00.00.FF.FF.75.00.00.00.00.00.00.6B (13)
[14:02:51][D][select:015]: 'Over Heating': Sending state 0 (Default) (index 0)
[14:02:51][D][sensor:094]: 'Pipe Temperature Mid': Sending state 24.00000 °C with 0 decimals of accuracy
[14:02:51][W][component:237]: Component lg_controller.climate took a long time for an operation (147 ms).
[14:02:51][W][component:238]: Components should block for at most 30 ms.
[14:02:51][D][sensor:094]: 'Uptime': Sending state 50.55000 s with 0 decimals of accuracy
[14:02:57][D][lg-controller:1351]: update
[14:02:57][D][lg-controller:899]: sending AA.E0.00.00.00.00.00.00.00.02.F1.21.CB (13)
[14:02:57][W][component:237]: Component lg_controller.climate took a long time for an operation (509 ms).
[14:02:57][W][component:238]: Components should block for at most 30 ms.
[14:03:03][D][lg-controller:1351]: update
[14:03:03][D][lg-controller:943]: received AA.E0.00.00.00.00.00.00.00.02.F1.21.CB (13)
[14:03:03][D][lg-controller:959]: verified send
[14:03:03][D][lg-controller:934]: sending AB.00.00.FF.FF.75.00.00.00.00.00.00.4B (13)
[14:03:03][W][component:237]: Component lg_controller.climate took a long time for an operation (515 ms).
[14:03:03][W][component:238]: Components should block for at most 30 ms.
[14:03:09][D][lg-controller:1351]: update
[14:03:09][D][lg-controller:943]: received AB.00.00.FF.FF.75.00.00.00.00.00.00.4B (13)
[14:03:09][D][lg-controller:959]: verified send
[14:03:09][D][lg-controller:943]: received C8.20.00.00.00.00.07.1E.00.00.00.00.58 (13)
[14:03:09][D][sensor:094]: 'Error Code': Sending state 0.00000  with 0 decimals of accuracy
[14:03:09][D][lg-controller:1074]: ignoring because pending change
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
JanM321, 2024-05-23:
> I miss the ability to set a specific air direction - I can set 6 vertical positions and 5 horizontal from the remote.

The horizontal angle can't be set because the protocol and LG wired controllers don't support it, unfortunately.

There's protocol support for setting the vertical direction, but I see in your log that the unit reports that it doesn't have this feature. Maybe LG chose not to implement this for some reason. They've done this with other features too, for example low-medium and medium-high fan speeds are available in the protocol but most units ignore these values even though they support these modes with the wireless remote.

>  Occasionally I get invalid checksum for a reason unknown to me (e.g. once every 30 minutes).

Maybe a hardware issue or something with the wiring.

> Would it be possible to modify the source code to use id: ac_serial?

Does adding `uart_id: ac_serial` to the climate's YAML code work?

DavidAntonin, 2024-05-24:
Thank you for the airflow information. Would it be possible to try to send a setup command for vertical flow - even if the unit doesn't publish it? With the fan it is also strange, using the remote I can set 5 speeds + breeze.
There was an idea in a previous post, to add an IR transmitter, to send commands that are not supported by the wired controller.

As for the UART, it is already listed in base.yaml:
```
uart:
  - id: ac_serial
    tx_pin: GPIO25
    rx_pin: GPIO26 # Keep in sync with RxPin in lg-controller.h
    baud_rate: 104
```
However, the actual component does not use id: ac_serial, it refers to UART in general.
Therefore, if I change the code to:
```
uart:
  - id: ac_serial
    tx_pin: GPIO25
    rx_pin: GPIO26 # Keep in sync with RxPin in lg-controller.h
    baud_rate: 104
  - id: pzem_serial
    tx_pin: GPIO5
    rx_pin: GPIO6
    baud_rate: 9600
```
an error occurs during compilation.
I don't know if it is possible to specify which UART (id) to use in the custom component. This is how it is described in the ESPHome UART documentation
```
  - uart.write:
      id: my_second_uart
      data: 'data to send'

```

JanM321, 2024-05-24:
@DavidAntonin What I was suggesting is to add `uart_id: ac_serial` here: https://github.com/JanM321/esphome-lg-controller/blob/main/esphome/base.yaml#L32

Does that work?

DavidAntonin, 2024-05-25:
@JanM321 Thank you, adding uart_id: ac_serial works and now I have power metering working. Now I will try add IR transmiter to get more functions of my AC

JanM321, 2024-06-01:
Great! I added `uart_id: ac_serial` to base.yaml. It's also nicer to be more explicit about this.

Closed 2024-06-01.

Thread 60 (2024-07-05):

Current Temperature missing

Arunas-g, 2024-07-05:
Hello. I have a problem getting "Current Temperature" from my LG TC07GQR air conditioner. I have another LG air conditioner, model PC12SQ, it works perfectly. In the logs, instead of the temperature, it says “nan°C”

`[15:01:01][D][climate:419]:   Current Temperature: nan°C`
`[15:01:01][D][climate:425]:   Target Temperature: 26.00°C`

At the same time, the air conditioner itself works normally, reacts to changes in “Target Temperature” and automatically changes the air flow rate. Air conditioner control is organized using "hardware-tiny". Please help me understand the reason for the incorrect display of the target temperature.

I attach logs and screenshots
[logs_Current Temperature nan C.txt](https://github.com/user-attachments/files/16108666/logs_Current.Temperature.nan.C.txt)
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

JanM321, 2024-07-05:
It's using `sensor.ac_lg_linas` as room temperature sensor. Is that a sensor you have available in Home Assistant? Can you show information about that one?

JanM321, 2024-07-05:
Basically your options are:
1. Set the "Internal Thermistor" setting to On to use the temperature value measured by the AC.
2. Make sure `sensor.ac_lg_linas` is a valid temperature sensor in Home Assistant because it will be *read* by the controller.

Arunas-g, 2024-07-05:
I apologize for the trouble :) I turned on "Internal Thermistor" and after that "Current Temperature" is displayed correctly in the logs.
Thank you!

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

JanM321, 2024-07-05:
No problem. I’m glad that works :)

Closed 2024-07-05.

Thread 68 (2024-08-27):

Cable connection color confirmation

Hadatko, 2024-08-27:
Hi, the cable i bought based on requirements and connector i should connect to looks differ in colors.
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
I wanted confirmation how to wire to the board.
Like: My red cable is gnd, My black wire is LIN and my yellow wire is 12V.

Btw great work ;)

Hadatko, 2024-08-27:
Yeah i made is as i wrote and it is working.

apppie123, 2025-04-20:
The cable you used in the picture is a JST-XH?
I'm a bit confused.

- In the LG manual of the PZCWRCG3 -which I believe is the extension cable for the wired remote display- I read that it is a MOLEX cable(typenumber not specified).
- The connector on the PCB inside the indoor unit looks like a JST-XH connector but with locking feature.
- I read that people had issues using the recommended cable from adafruit(Adafruit 4873) to the green extension cable in your picture, but that the same adafruit cable does fit into the connector on the PCB.

JanM321, 2025-04-21:
@apppie123 This isn't documented very well by LG unfortunately. I use the LG cables (PZCWRC1 I think?) and the Adafruit 4873 works well with those.

When I started this project I didn't know how often I'd need to access the controller so using these long LG cables was the simplest option. JST-XH was the closest connector I could find at the time, but it's not an exact match.

joeblack2k, 2025-06-13:
> Yeah i made it as i wrote and it is working.

in the end, did you match the colors ? so "Red,Yellow,Black" ?

joeblack2k, 2025-06-13:
I'm not very experienced with electronics, so I'm trying to understand it correctly. On the air conditioner side, red = 12V, black = ground, and yellow = data/line, right?
If I follow that same order when connecting to the board, everything should work fine, correct?

On the ESP side, it's:

Pin 1 = GND (black)

Pin 2 = line bus (yellow)

Pin 3 = 12V (red)

So I just need to make sure the wires from the air conditioner are connected in that order to the ESP32 using Dupont cables.

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

Closed 2024-08-27.

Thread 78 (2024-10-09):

Turn display off

evertide, 2024-10-09:
Feature request?

First of all great work on the project!. The biggest gain is no sound with changes! !

the current remote control (IR) can switch off the display whilst staying powered on.
This is great during the night.

Can this be done with the pcb as well?

regards

JanM321, 2024-10-12:
Unfortunately this isn't possible, at least with my indoor units. Newer controllers have some settings for this in newer protocol messages but I haven't seen them actually being used.

You could test this by changing the display light setting with the IR remote and checking the esphome log output.

The LG ThinQ integration for Home Assistant has this setting. The Wifi module uses a very different protocol with a different set of features.

evertide, 2024-10-14:
This is the log when switching the light off
[19:26:01][D][lg-controller:1354]: update
[19:26:07][D][lg-controller:1354]: update
[19:26:07][D][lg-controller:946]: received C8.43.00.00.00.04.03.55.00.00.00.00.32 (13)
[19:26:07][D][sensor:094]: 'Error Code': Sending state 0.00000  with 0 decimals of accuracy
[19:26:07][D][climate:396]: 'Mancave 2 Airco' - Sending state:
[19:26:07][D][climate:399]:   Mode: COOL
[19:26:07][D][climate:404]:   Fan Mode: HIGH
[19:26:07][D][climate:416]:   Swing Mode: OFF
[19:26:07][D][climate:419]:   Current Temperature: 20.50°C
[19:26:07][D][climate:425]:   Target Temperature: 18.00°C
[19:26:07][D][climate:396]: 'Mancave 2 Airco' - Sending state:
[19:26:07][D][climate:399]:   Mode: COOL
[19:26:07][D][climate:404]:   Fan Mode: HIGH
[19:26:07][D][climate:416]:   Swing Mode: OFF
[19:26:07][D][climate:419]:   Current Temperature: 20.50°C
[19:26:07][D][climate:425]:   Target Temperature: 18.00°C
[19:26:07][D][lg-controller:946]: received C8.43.00.00.00.04.03.55.00.00.00.00.32 (13)
[19:26:07][D][sensor:094]: 'Error Code': Sending state 0.00000  with 0 decimals of accuracy
[19:26:07][D][climate:396]: 'Mancave 2 Airco' - Sending state:
[19:26:07][D][climate:399]:   Mode: COOL
[19:26:07][D][climate:404]:   Fan Mode: HIGH
[19:26:07][D][climate:416]:   Swing Mode: OFF
[19:26:07][D][climate:419]:   Current Temperature: 20.50°C
[19:26:07][D][climate:425]:   Target Temperature: 18.00°C

This is when switching it on again
[19:25:31][D][lg-controller:1354]: update
[19:25:31][D][lg-controller:946]: received A8.42.00.00.00.04.03.54.00.00.00.00.10 (13)
[19:25:31][D][lg-controller:962]: verified send
[19:25:37][D][lg-controller:1354]: update
[19:25:37][D][lg-controller:946]: received C8.42.00.00.00.04.03.56.00.00.00.00.32 (13)
[19:25:37][D][sensor:094]: 'Error Code': Sending state 0.00000  with 0 decimals of accuracy
[19:25:37][D][climate:396]: 'Mancave 2 Airco' - Sending state:
[19:25:37][D][climate:399]:   Mode: COOL
[19:25:37][D][climate:404]:   Fan Mode: HIGH
[19:25:37][D][climate:416]:   Swing Mode: OFF
[19:25:37][D][climate:419]:   Current Temperature: 21.00°C
[19:25:37][D][climate:425]:   Target Temperature: 18.00°C
[19:25:37][D][climate:396]: 'Mancave 2 Airco' - Sending state:
[19:25:37][D][climate:399]:   Mode: COOL
[19:25:37][D][climate:404]:   Fan Mode: HIGH
[19:25:37][D][climate:416]:   Swing Mode: OFF
[19:25:37][D][climate:419]:   Current Temperature: 21.00°C
[19:25:37][D][climate:425]:   Target Temperature: 18.00°C
[19:25:37][D][lg-controller:946]: received C8.42.00.00.00.04.03.56.00.00.00.00.32 (13)
[19:25:37][D][sensor:094]: 'Error Code': Sending state 0.00000  with 0 decimals of accuracy
[19:25:37][D][climate:396]: 'Mancave 2 Airco' - Sending state:
[19:25:37][D][climate:399]:   Mode: COOL
[19:25:37][D][climate:404]:   Fan Mode: HIGH
[19:25:37][D][climate:416]:   Swing Mode: OFF
[19:25:37][D][climate:419]:   Current Temperature: 21.00°C
[19:25:37][D][climate:425]:   Target Temperature: 18.00°C

JanM321, 2024-10-15:
Unfortunately it's not sending any settings for the display light, just the regular status messages. I see the same thing with my units.

I really wish LG had designed this to at least offer the same features as the IR remote.

evertide, 2024-10-15:
Thanks, Lets close the issue then. ( But keep it on the wish list with future firmware updates ;-) )

Closed 2024-10-15.

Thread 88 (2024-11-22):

Tiny PCB and backfeding

rrooggiieerr, 2024-11-22:
Could it be that the Tiny PCB can't handle backfeeding? I plugged in a USB in my ESP to do some debugging while power also being connected trough the Tiny PCB and it seems something in the Tiny PCB died. When removing the USB the ESP won't respond anymore

JanM321, 2024-11-22:
It's possible the ESP32 board died because they support being powered from 3.3V/5V/USB but not more than one of these:

https://docs.espressif.com/projects/esp-idf/en/v5.1/esp32/hw-reference/esp32/get-started-devkitc.html
> **Warning**
> The power supply must be provided using one and only one of the options above, otherwise the board and/or the power supply source can be damaged.

rrooggiieerr, 2024-11-22:
No, the ESP32 still works

rrooggiieerr, 2024-11-22:
I still have 6 of the Tiny PCB boards laying around, so not really a big problem for me. But maybe add a warning in the documentation not to wire both USB and CN_REMO

Closed 2025-02-12.

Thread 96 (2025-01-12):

Compatibility with E12SQ

ricard0g0mes, 2025-01-12:
I'm trying to use this with my AC.
It's the LG E12SQ and it has the JST connector.

I have the PCB (hardware-tiny) assembled by JLCPCB, but it doen't work.
Could this model have different settings, supply...?

JanM321, 2025-01-13:
I'd expect the E12SQ to be compatible. You flashed the firmware? Does the ESP32 power on?

ricard0g0mes, 2025-01-13:
Yes and yes. I've used a M5 atom (connected to pinout in the PCB) and changed to the correct gpios of the m5. I also activated the webpage and it shows all the entities, but always trying to connect and failing. I will try with the esp32 dev board. But it should work with this...

ricard0g0mes, 2025-01-20:
Hello.
It's working. I think it was a faulty pcb from JLCPCB
By the way, i used esphome builder embebbed in home assistant.
If anyone needs it, here is the code:

`external_components:
  # use rtttl and dfplayer from ESPHome's dev branch in GitHub
  - source:
      type: git
      url: https://github.com/JanM321/esphome-lg-controller
      ref: dev
    components: [lg_controller]

substitutions:
  device_name: escritorio
  device_type: ac_lg
  device_id: ${device_type}_${device_name}

  # The input temperature sensor in HA.
  temperature_sensor_entity_id: sensor.escritorio_th_temperature # XXX

  # Set to "true" if the temperature sensor and Home Assistant use Fahrenheit instead of Celsius.
  fahrenheit: "false" # XXX

  # If you're connecting a single controller, this should be set to "false".
  is_slave_controller: "false"

esphome:
  name: ${device_id}

esp32:
  board: esp32dev
  framework:
    type: arduino
    #type: esp-idf

# Enable logging
logger:

# Enable Home Assistant API
api:
  encryption:
    key: "XXXXXXXXXXXXXXXX"

ota:
  - platform: esphome
    password: "XXXXXXXXXXXXXXXXXXXXXXX"

wifi:
  ssid: !secret wifi_ssid
  password: !secret wifi_password

  # Enable fallback hotspot (captive portal) in case wifi connection fails
  ap:
    ssid: "Ac-Lg-Esc Fallback Hotspot"
    password: "crz9FrYsVXNH"

captive_portal:

# Enable Web server (optional).
web_server:
  port: 80

uart:
  - id: ac_serial
    tx_pin: GPIO25
    rx_pin:
      number: GPIO26 # Keep in sync with rx_pin below.
      allow_other_uses: true
    baud_rate: 104

time:
  - platform: homeassistant
    id: ${device_id}_homeassistant_time

sensor:
  - id: temp_sensor
    platform: homeassistant
    internal: true
    entity_id: ${temperature_sensor_entity_id}
  # Uptime sensor.
  - platform: uptime
    name: ${device_id} Uptime

  # WiFi Signal sensor.
  - platform: wifi_signal
    name: ${device_id} WiFi Signal
    id: ${device_id}_${device_id}_wifi_signal_db
    update_interval: 60s

  - platform: copy # Reports the WiFi signal strength in %
    source_id: ${device_id}_${device_id}_wifi_signal_db
    name: "${device_id} WiFi Signal Percent"
    filters:
      - lambda: return min(max(2 * (x + 100.0), 0.0), 100.0);
    unit_of_measurement: "Signal %"
    entity_category: "diagnostic"
    device_class: ""

climate:
  - platform: lg_controller
    id: ${device_id}
    name: ${device_type} ${device_name}
    uart_id: ac_serial
    rx_pin:
      number: GPIO26 # Keep in sync with rx_pin above.
      allow_other_uses: true
    fahrenheit: ${fahrenheit}
    is_slave_controller: ${is_slave_controller}
    temperature_sensor: temp_sensor
    vane1:
      name: Airflow 1 Up/Down
      id: ${device_id}_vane_position_1
      icon: mdi:arrow-up-down
    vane2:
      name: ${device_id} Airflow 2 Up/Down
      id: ${device_id}_vane_position_2
      icon: mdi:arrow-up-down
    vane3:
      name: ${device_id} Airflow 3 Up/Down
      id: ${device_id}_vane_position_3
      icon: mdi:arrow-up-down
    vane4:
      name: ${device_id} Airflow 4 Up/Down
      id: ${device_id}_vane_position_4
      icon: mdi:arrow-up-down
    overheating:
      name: ${device_id} Over Heating
      id: ${device_id}_overheating
      icon: mdi:heating-coil
    fan_speed_slow:
      name: ${device_id} Fan Speed Slow
      id: ${device_id}_fan_speed_slow
      icon: mdi:fan-chevron-down
      mode: box
    fan_speed_low:
      name: ${device_id} Fan Speed Low
      id: ${device_id}_fan_speed_low
      icon: mdi:fan-speed-1
      mode: box
    fan_speed_medium:
      name: ${device_id} Fan Speed Medium
      id: ${device_id}_fan_speed_medium
      icon: mdi:fan-speed-2
      mode: box
    fan_speed_high:
      name: ${device_id} Fan Speed High
      id: ${device_id}_fan_speed_high
      icon: mdi:fan-speed-3
      mode: box
    sleep_timer:
      name: ${device_id} "Sleep Timer (minutes)"
      id: ${device_id}_sleep_timer
      icon: mdi:timer-outline
      mode: box
    error_code:
      name: ${device_id} Error Code
      id: ${device_id}_error_code
      icon: mdi:alert-circle-outline
    pipe_temp_in:
      name: ${device_id} Pipe Temperature In
      id: ${device_id}_pipe_temperature_in
      icon: mdi:thermometer
      unit_of_measurement: "°C"
    pipe_temp_mid:
      name: ${device_id} Pipe Temperature Mid
      id: ${device_id}_pipe_temperature_mid
      icon: mdi:thermometer
      unit_of_measurement: "°C"
    pipe_temp_out:
      name: ${device_id} Pipe Temperature Out
      id: ${device_id}_pipe_temperature_out
      icon: mdi:thermometer
      unit_of_measurement: "°C"
    defrost:
      name: ${device_id} Defrost
      id: ${device_id}_defrost
      icon: mdi:snowflake-melt
    preheat:
      name: ${device_id} Preheat
      id: ${device_id}_preheat
      icon: mdi:heat-wave
    outdoor:
      name: ${device_id} Outdoor Unit
      id: ${device_id}_outdoor
      icon: mdi:fan
    auto_dry_active:
      name: ${device_id} Auto Dry Active
      id: ${device_id}_auto_dry_active
      icon: mdi:fan-clock
    purifier:
      name: ${device_id} Air Purifier
      id: ${device_id}_air_purifier
      icon: mdi:pine-tree
    internal_thermistor:
      name: ${device_id} Internal Thermistor
      id: ${device_id}_internal_thermistor
      icon: mdi:thermometer
    auto_dry:
      name: ${device_id} Auto Dry
      id: ${device_id}_auto_dry
      icon: mdi:fan-clock    `

JanM321, 2025-01-25:
I'm glad it works now.

Closed 2025-01-25.

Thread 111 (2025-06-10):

Unknown fan and swing mode errors with LG S09EQR using ESPHome lg-controller module

lagomCat, 2025-06-10:
Hello,

I’m using the ESPHome lg-controller module with an LG S09EQR air conditioner. The hardware is assembled on a breadboard following the project schematic, with the LIN driver TJA1027T.

The ESP module successfully connects to the AC unit — when the ESP is disconnected, the AC shows CH03 error (no wired remote). When reconnected, the error disappears, indicating the module is detected.
However, the AC does not respond to commands sent by the module.
Here is the relevant log snippet:

[19:06:56][D][lg-controller:1358]: update
[19:07:08][E][lg-controller:750]: unknown fan mode, using Medium
[19:07:08][E][lg-controller:774]: unknown swing mode
[19:07:08][D][lg-controller:853]: sending A8.22.00.00.00.00.16.20.40.00.80.00.95 (13)
[19:07:14][D][lg-controller:950]: received A8.22.00.00.00.00.16.20.40.00.80.00.95 (13)
[19:07:14][D][lg-controller:966]: verified send
[19:07:32][E][lg-controller:750]: unknown fan mode, using Medium
[19:07:32][E][lg-controller:774]: unknown swing mode

It seems the fan mode and swing mode returned by the AC are unknown to the module, which falls back to defaults and prevents proper command execution.
Could you please advise on how to handle this model or update the firmware to support these modes correctly?
Thanks in advance!

[19:19:02][D][lg-controller:1358]: update
[19:19:02][D][lg-controller:950]: received A8.22.00.00.00.00.16.20.40.00.80.00.95 (13)
[19:19:02][D][lg-controller:966]: verified send
[19:19:08][D][lg-controller:1358]: update
[19:19:12][D][climate:011]: 'LG Bed Room' - Setting
[19:19:12][D][climate:040]:   Target Temperature: 24.00
[19:19:12][D][climate:396]: 'LG Bed Room' - Sending state:
[19:19:12][D][climate:399]:   Mode: COOL
[19:19:12][D][climate:416]:   Swing Mode: UNKNOWN
[19:19:12][D][climate:419]:   Current Temperature: 26.00°C
[19:19:12][D][climate:425]:   Target Temperature: 24.00°C
[19:19:14][D][lg-controller:1358]: update
[19:19:15][E][lg-controller:750]: unknown fan mode, using Medium
[19:19:15][E][lg-controller:774]: unknown swing mode
[19:19:15][D][lg-controller:853]: sending A8.23.00.00.00.00.19.20.40.00.80.00.91 (13)
[19:19:20][D][lg-controller:1358]: update
[19:19:20][D][lg-controller:950]: received A8.23.00.00.00.00.19.20.40.00.80.00.91 (13)
[19:19:20][D][lg-controller:966]: verified send
[19:19:21][E][lg-controller:876]: Unexpected missing previous CA/AA message
[19:19:21][D][esp32.preferences:114]: Saving 1 preferences to flash...
[19:19:21][D][esp32.preferences:143]: Saving 1 preferences to flash: 0 cached, 1 written, 0 failed
[19:19:26][D][lg-controller:1358]: update
[19:19:32][D][lg-controller:1358]: update

JanM321, 2025-06-10:
Does the controller actually *receive* messages from the AC? These messages would start with C8 instead of A8. In the snippets you posted it's just the controller sending things.

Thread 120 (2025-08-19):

Hardware-FeatherS3 - ESP32-DevKitC-32E work ???

Sakab001, 2025-08-19:
Hi everyone, I got a bit mixed up with my order and started having the hardware “Feather S3” (May 2025) manufactured with JLCPCB, and I accidentally ordered an ESP32-DevKitC-32E for it. Since then, I’ve learned that the Feather is narrower and I can’t plug them together.
[https://i.ebayimg.com/images/g/gL8AAOSwv25jz9FO/s-l1600.webp](url)
[https://www.ebay.com/itm/116583890495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](url)

If I rewire the necessary pins with wires, will it work, or do I absolutely need to get a Feather S3? If it won’t work and I do need the S3, is this version okay? The one I found differs from the S3 listed in the description. It is also a Feather S3, but the connector at the end and one or two components are different.

cure, 2025-08-20:
Hey, I added the "FeatherS3" (May 2025) variant.

It is designed to work with [Unexpected Maker's "FeatherS3"](https://esp32s3.com/feathers3.html), which has a different form factor than the ESP32-DevKitC-32E, as you discovered.

There are many ESP32 boards in the Feather form factor. The one you found on Ebay is the "Adafruit ESP32-S3 Feather with 4MB Flash 2MB PSRAM - STEMMA QT / Qwiic", which is documented extensively [on the Adafruit website](https://learn.adafruit.com/adafruit-esp32-s3-feather/overview). The physical form factor is the same since they are both "Feather" boards.

The next most important thing to verify is that the pinouts match for the pins used by the esphome-lg-controller:
* Adafruit ESP32-S3 Feather: [pinout](https://cdn-learn.adafruit.com/assets/assets/000/110/811/original/adafruit_products_Adafruit_Feather_ESP32-S3_Pinout.png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)
* Unexpected Maker's FeatherS3: [pinout](https://esp32s3.com/feathers3.html#img1)

The 3V3 and GND pins that are used by the esphome-lg-controller board are in the same position on both boards. The LINBUS RX/TX GPIO numbers are swapped, but you can just tweak the [base.yaml](https://github.com/JanM321/esphome-lg-controller/blob/main/esphome/base.yaml) accordingly.

There is one caveat: I picked the FeatherS3 because it explicitly supports [being powered from the 3V3 pin](https://help.unexpectedmaker.com/index.php/knowledge-base/can-i-power-my-board-from-the-3v3-pin/). For the Adafruit's Feather ESP32-S3, the [power management documentation](https://learn.adafruit.com/adafruit-esp32-s3-feather/power-management) says that it is technically possible to do the same but it is not recommended, I quote:

========================================
The Feather is not designed for external power supplies - this is a design decision to make the board compact and low cost. It is not recommended, but technically possible:

* Connect an external 3.3V power supply to the 3V and GND pins. Not recommended, this may cause unexpected behavior and the EN pin will no longer work. Also this doesn't provide power on BAT or USB and some Feathers/Wings use those pins for high current usages. You may end up damaging your Feather.

========================================

Would it work anyway? Maybe? I have not tried. Not providing power on BAT or USB is no problem for this use case (there would be no other Feathers/Wings connected). The EN pin is not connected, so that's no issue either.

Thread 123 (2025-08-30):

The Feather S3 is not communicating with the PREMTB100 :(

Sakab001, 2025-08-30:
Hi everyone! Status update and a request for help.

First of all, I don’t have an air conditioner, but an LG heat recovery ventilator (LG LZ-H035GBA5) and a PREMTB100.
The Feather S3 and its corresponding board have arrived. I connected it, flashed it, and added it to Home Assistant. It connects to Wi-Fi, Home Assistant recognizes it, and no errors are shown. I can toggle the buttons, but nothing happens.

I tried all the options: heating, cooling, fan only (low, medium, high fan speed) – but nothing changes on the original controller.

What I noticed is that when I first connected it while it was powered on, the display changed and looked like this:
[(image)](https://i.ibb.co/tpF4sVYD/viber-k-p-2025-08-30-15-12-58-424.jpg)

Then, after I power-cycled it with the connection in place, the original display returned, but its color seemed to change:
[(image)](https://i.ibb.co/7dNWmBG8/viber-k-p-2025-08-30-15-12-58-444.jpg)

Another thing I noticed with the Feather S3 is that once it was powered only by the PREMTB100, not all 4 LEDs were blinking—only the two closer to the USB-C port. The two on the back did not light up or blink.

Also, I didn’t pay attention before, so I’m not sure if it was like this earlier, but now this chip gets extremely hot—so hot I can’t keep my finger on it. I’m not sure if that’s normal. Naturally, when it’s connected to the PREMTB100, it does not get any additional power from a separate Type-C adapter.
[(image)](https://i.ibb.co/tTJySM8w/feather.jpg)

Other than that, it doesn’t show any errors, it connects to Wi-Fi, and Home Assistant recognizes it.

Here are my YAML files:
[(image)](https://i.ibb.co/20FqL4X6/yaml.jpg)
[(image)](https://i.ibb.co/8nHCzKqm/baseyaml.jpg)

What did I do wrong? :/

Sakab001, 2025-08-30:
I don't know if this helps, but I was able to extract this log:
ESP-ROM:esp32s3-20210327

[I][logger:165]: Log initialized

[C][safe_mode:082]: There have been 0 suspected unsuccessful boot attempts

[D][esp32.preferences:142]: Writing 1 items: 0 cached, 1 written, 0 failed

[I][app:090]: Running through setup()

[C][component:164]: Setup uart took 0ms

[D][climate:396]: 'LG Living Room' - Sending state:

[D][climate:399]:   Mode: FAN_ONLY

[D][climate:425]:   Target Temperature: 30.00°C

[D][switch:0[D][lg-controller:1358]: update

[E][lg-controller:750]: unknown fan mode, using Medium

[E][lg-controller:774]: unknown swing mode

[D][lg-controller:853]: sending A8.2B.00.00.00.00.0F.14.40.00.80.00.E3 (13)

[W][component:423]: lg_controller.climate took a long time for an operation (510                                                                                                                                                                                                                                              ms)

[W][component:424]: Components should block for at most 30 ms

[W][component:423]: api took a long time for an operation (512 ms)

[W][component:424]: Components should block for at most 30 ms

[D][lg-controller:1358]: update

[E][lg-controller:876]: Unexpected missing previous CA/AA message

[D][lg-controller:1358]: update

JanM321, 2025-08-31:
Your unit may use a protocol that's different from the one used for AC units. There's some information in #33

From your log file it looks like the controller is sending messages but not receiving anything. I'd expect to see at least some data coming from the PREMTB100 if it's not set to slave mode. You should double check the data wire (the middle one) is connected properly.

Sakab001, 2025-08-31:
Hi, thank you for your reply. I will check the signal cable, but since the display has also changed, that shouldn’t be an issue. I looked at the post, and the author of the post has the same type of ventilator as I do, only theirs is the smaller one, while mine is the higher-performance version. I would only like to integrate the commands listed in this table into Home Assistant. Are these the commands that are included in the basic protocol file that has been uploaded? How can I read what code the PREMTB is sending? Because if I can read those 6–7 codes, I will extract them and integrate them into my own protocol file.

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

JanM321, 2025-09-01:
> Should I be seeing the command line sent by the PREMTB here?

The log you posted yesterday, that's where you should see messages that are sent/received. I only use the esphome command line and there you can use `esphome logs ..` to watch new log messages.

> Once I have the codes, exactly which file should I open and modify for the command line?

lg-controller.h is where the AC protocol is implemented.

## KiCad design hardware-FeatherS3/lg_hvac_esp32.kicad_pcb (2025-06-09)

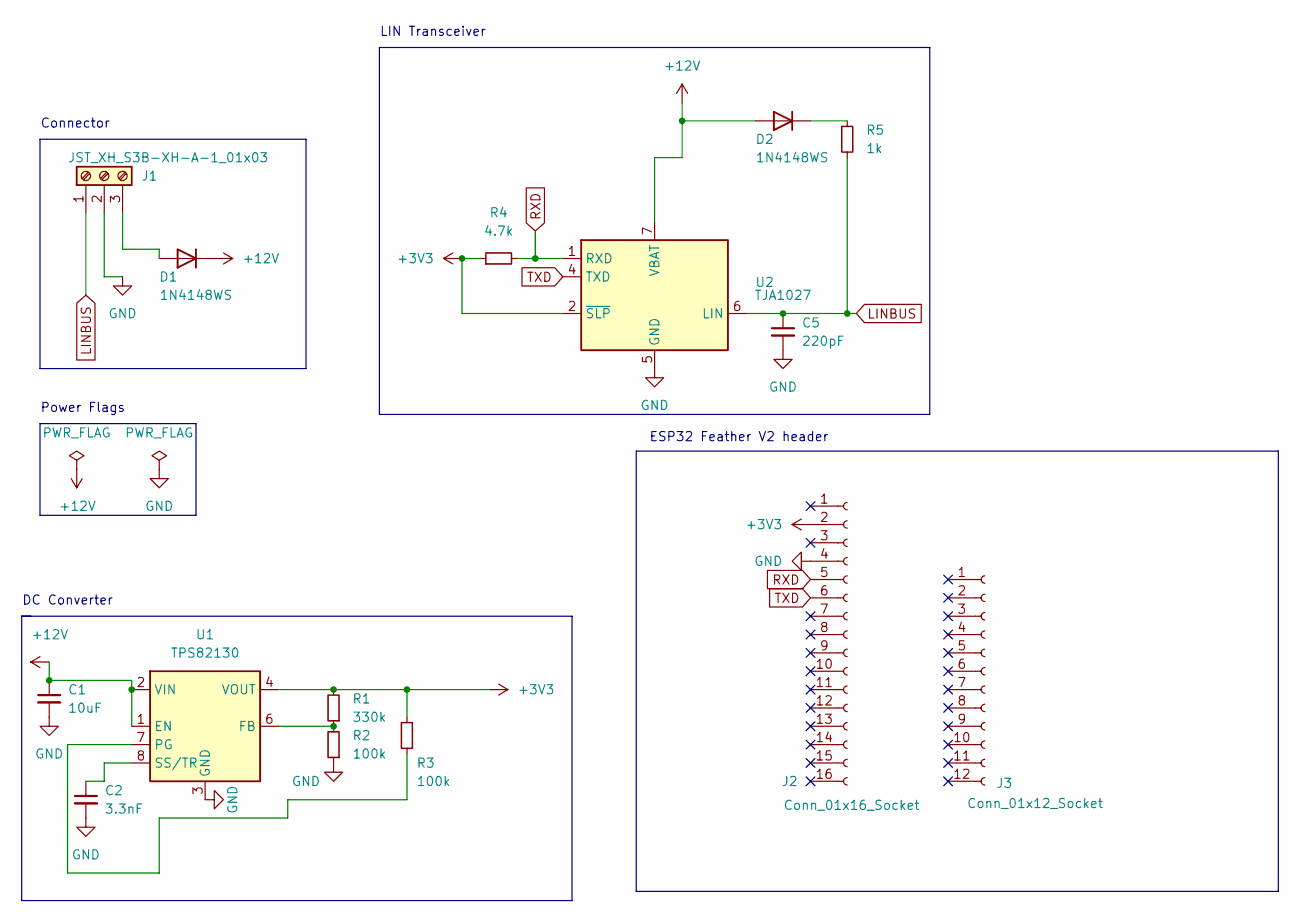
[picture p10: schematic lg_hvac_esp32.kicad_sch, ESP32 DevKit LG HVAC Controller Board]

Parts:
C1: 10uF; C_1210_3225Metric; LCSC C92834
C2: 3.3nF; C_0402_1005Metric; LCSC C26404
C5: 220pF; C_0402_1005Metric; LCSC C343058
D1, D2: 1N4148WS; D_SOD-323; LCSC C727111
J1: JST_XH_S3B-XH-A-1_01x03; JST_XH_S3B-XH-A-1_1x03_P2.50mm_Horizontal; LCSC C157928
J2: Conn_01x16_Socket; PinSocket_1x16_P2.54mm_Vertical
J3: Conn_01x12_Socket; PinSocket_1x12_P2.54mm_Vertical
R1: 330k; R_0805_2012Metric; LCSC C17629
R2, R3: 100k; R_0805_2012Metric; LCSC C149504
R4: 4.7k; R_0805_2012Metric; LCSC C17673
R5: 1k; R_0805_2012Metric; LCSC C17513
U1: TPS82130; Texas_SIL0008D_MicroSiP-8-1EP_2.8x3mm_P0.65mm_EP1.1x1.9mm_T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; LCSC C473914
U2: TJA1027; SOIC-8_3.9x4.9mm_P1.27mm; LCSC C194371

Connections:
+3V3: J2.2, R1.2, R3.2, R4.1, U1.4 (VOUT), U1.5 (VOUT), U2.2 (~SLP)
+12V: C1.1, D1.1 (K), D2.2 (A), U1.1 (EN), U1.2 (VIN), U2.7 (VBAT)
GND: C1.2, C2.2, C5.2, J1.2, J2.4, R2.1, U1.3 (GND), U1.9 (GND), U2.5 (GND)
LINBUS: C5.1, J1.1, R5.2, U2.6 (LIN)
unnamed: D1.2 (A), J1.3
unnamed: D2.1 (K), R5.1
unnamed: R1.1, R2.2, U1.6 (FB)
unnamed: R3.1, U1.7 (PG)
unnamed: C2.1, U1.8 (SS/TR)
RXD: J2.5, R4.2, U2.1 (RXD)
TXD: J2.6, U2.4 (TXD)

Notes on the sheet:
DC Converter
Connector
LIN Transceiver
Power Flags
ESP32 Feather V2 header

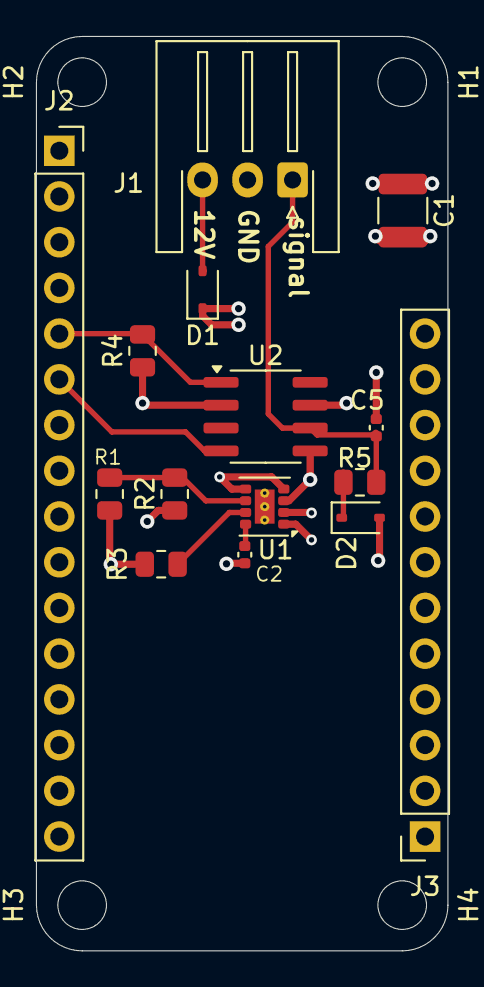
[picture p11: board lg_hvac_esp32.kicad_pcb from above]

Board: 4 copper layers, 22.9 x 50.8 mm, 19 parts (0 on the bottom side), 11 nets.

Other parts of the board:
H1, H2, H3, H4: MountingHole; MountingHole_2.7mm_M2.5

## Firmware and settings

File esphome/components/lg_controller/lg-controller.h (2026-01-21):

#pragma once

#include "esphome.h"
#include "esphome/components/uart/uart.h"

static const char* const TAG = "lg-controller";

namespace esphome::lg_controller {

static constexpr size_t MIN_TEMP_SETPOINT = 16;
static constexpr size_t MAX_TEMP_SETPOINT = 30;

class LgSwitch final : public switch_::Switch {
    void write_state(bool value) override {
        publish_state(value);
    }

public:
    void restore_and_set_mode(switch_::SwitchRestoreMode mode) {
        set_restore_mode(mode);
        if (auto state = get_initial_state_with_restore_mode()) {
            write_state(*state);
        }
    }
};

class LgSelect final : public select::Select {
    void control(const std::string& value) override {
        if (this->current_option() != value) {
            this->publish_state(value); 
        }
    }
};

class LgNumber final : public number::Number {
    void control(float value) override {
        if (this->state != value) {
            this->publish_state(value); 
        }
    }
};

// The LG protocol always uses Celsius. The HA/ESPHome climate component internally
// converts between Fahrenheit and Celsius. Values from the Home Assistant room temperature sensor
// are not converted automatically so can be Celsius or Fahrenheit.
//
// Unfortunately LG uses their own Fahrenheit/Celsius mapping that's different from what you'd
// expect. For example, 78F is ~25.5C, but LG controllers will send 26C for 78F. A value of 25.5C
// would be interpreted by the AC as 77F.
//
// This class has some functions to convert between Fahrenheit, Celsius and "LG-Celsius" (values
// we send to or receive from the unit). This ensures Home Assistant and the LG unit always agree
// on the setpoint in Fahrenheit.
//
// These conversions are only used in Fahrenheit mode.
class TempConversion {
private:
    static constexpr int8_t FahToLGCel[] = {
        0  /* 32  */, 1  /* 33  */, 2  /* 34  */, 3  /* 35  */, 4  /* 36  */,
        5  /* 37  */, 6  /* 38  */, 7  /* 39  */, 8  /* 40  */, 10 /* 41  */,
        12 /* 42  */, 13 /* 43  */, 14 /* 44  */, 15 /* 45  */, 16 /* 46  */,
        17 /* 47  */, 18 /* 48  */, 19 /* 49  */, 20 /* 50  */, 21 /* 51  */,
        22 /* 52  */, 23 /* 53  */, 24 /* 54  */, 25 /* 55  */, 26 /* 56  */,
        27 /* 57  */, 28 /* 58  */, 30 /* 59  */, 32 /* 60  */, 33 /* 61  */,
        34 /* 62  */, 35 /* 63  */, 36 /* 64  */, 37 /* 65  */, 38 /* 66  */,
        39 /* 67  */, 40 /* 68  */, 41 /* 69  */, 42 /* 70  */, 43 /* 71  */,
        44 /* 72  */, 45 /* 73  */, 46 /* 74  */, 47 /* 75  */, 48 /* 76  */,
        50 /* 77  */, 52 /* 78  */, 53 /* 79  */, 54 /* 80  */, 55 /* 81  */,
        56 /* 82  */, 57 /* 83  */, 58 /* 84  */, 59 /* 85  */, 60 /* 86  */,
        61 /* 87  */, 62 /* 88  */, 63 /* 89  */, 64 /* 90  */, 65 /* 91  */,
        66 /* 92  */, 67 /* 93  */, 68 /* 94  */, 70 /* 95  */, 72 /* 96  */,
        73 /* 97  */, 74 /* 98  */, 75 /* 99  */, 76 /* 100 */, 77 /* 101 */,
        78 /* 102 */, 79 /* 103 */, 80 /* 104 */
    };
    static constexpr int8_t LGCelToCelAdjustment[] = {
         0 /* 0    */,  0 /* 0.5  */,  0 /* 1.0  */,  0 /* 1.5  */,  0 /* 2.0  */,
         1 /* 2.5  */,  1 /* 3.0  */,  1 /* 3.5  */,  1 /* 4.0  */,  0 /* 4.5  */,
         0 /* 5.0  */, -1 /* 5.5  */, -1 /* 6.0  */, -1 /* 6.5  */, -1 /* 7.0  */,
        -1 /* 7.5  */,  0 /* 8.0  */,  0 /* 8.5  */,  0 /* 9.0  */,  0 /* 9.5  */,
         0 /* 10.0 */,  0 /* 10.5 */,  0 /* 11.0 */,  0 /* 11.5 */,  0 /* 12.0 */,
         1 /* 12.5 */,  1 /* 13.0 */,  1 /* 13.5 */,  1 /* 14.0 */,  0 /* 14.5 */,
         0 /* 15.0 */, -1 /* 15.5 */, -1 /* 16.0 */, -1 /* 16.5 */, -1 /* 17.0 */,
        -1 /* 17.5 */,  0 /* 18.0 */,  0 /* 18.5 */,  0 /* 19.0 */,  0 /* 19.5 */,
         0 /* 20.0 */,  0 /* 20.5 */,  0 /* 21.0 */,  0 /* 21.5 */,  0 /* 22.0 */,
         1 /* 22.5 */,  1 /* 23.0 */,  1 /* 23.5 */,  1 /* 24.0 */,  0 /* 24.5 */,
         0 /* 25.0 */, -1 /* 25.5 */, -1 /* 26.0 */, -1 /* 26.5 */, -1 /* 27.0 */,
        -1 /* 27.5 */,  0 /* 28.0 */,  0 /* 28.5 */,  0 /* 29.0 */,  0 /* 29.5 */,
         0 /* 30.0 */,  0 /* 30.5 */,  0 /* 31.0 */,  0 /* 31.5 */,  0 /* 32.0 */,
         1 /* 32.5 */,  1 /* 33.0 */,  1 /* 33.5 */,  1 /* 34.0 */,  0 /* 34.5 */,
         0 /* 35.0 */, -1 /* 35.5 */, -1 /* 36.0 */, -1 /* 36.5 */, -1 /* 37.0 */,
        -1 /* 37.5 */,  0 /* 38.0 */,  0 /* 38.5 */,  0 /* 39.0 */,  0 /* 39.5 */,
         0 /* 40.0 */
    };

public:
    // Convert from Fahrenheit to LG-Celsius (using the LG-compatible conversion).
    static float fahrenheit_to_lgcelsius(float temp) {
        int temp_int = int(round(temp));
        if (temp_int < 32 || temp_int > 104) {
            return esphome::fahrenheit_to_celsius(temp);
        }
        int8_t val = FahToLGCel[temp_int - 32];
        return float(val / 2) + ((val & 1) ? 0.5f : 0.0f);
    }
    // Convert an LG-Celsius value to Celsius. This is done to ensure the LG unit and HA agree
    // on the value in Fahrenheit. For example, the unit sends 78F as 26C (LG Celsius), but HA
    // would convert this to 78.8F => 79F. To work around this, we adjust 26C to 25.5C because
    // this maps to 78F in HA.
    static float lgcelsius_to_celsius(float temp) {
        int index = int(temp * 2);
        if (index < 0 || index >= sizeof(LGCelToCelAdjustment)) {
            return temp;
        }
        int8_t adjustment = LGCelToCelAdjustment[index];
        if (adjustment == -1) {
            return temp - 0.5;
        }
        if (adjustment == 1) {
            return temp + 0.5;
        }
        return temp;
    }
    static float celsius_to_lgcelsius(float temp) {
        float fahrenheit = esphome::celsius_to_fahrenheit(temp);
        return fahrenheit_to_lgcelsius(fahrenheit);
    }
};
constexpr int8_t TempConversion::FahToLGCel[];
constexpr int8_t TempConversion::LGCelToCelAdjustment[];
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

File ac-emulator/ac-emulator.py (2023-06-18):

# Very basic AC emulator for testing controllers. Requires the pyserial module.
#
# Typical usage on Linux is like this:
#
#    $ python3 ac-emulator.py /dev/ttyUSB0
#
# This has been tested with the LG PREMTB001 controller connected via a LIN bus
# transceiver to a PL2303 TTL USB Serial Port adapter.

import datetime
import time
import sys
import serial

class ACEmulator:
    _last_sent_time = None
    _last_received_time = None
    _last_status_response = None

    def __init__(self, serial_port):
        self._serial = serial.Serial(serial_port, baudrate=104, timeout=0.3)

    def calc_checksum(self, msg):
        assert len(msg) == 12
        return (sum(msg) & 0xFF) ^ 0x55

    def loop(self):
        buffer = b""
        while True:
            newpkt = self._serial.read(1)
            if not newpkt:
                buffer = b""
                if self._last_received_time and time.time() - self._last_received_time > 2:
                    self.send_timed()
            else:
                buffer += newpkt
            if len(buffer) == 13:
                self.process(buffer)
                buffer = b""
            assert len(buffer) < 13

    def process(self, buffer):
        self._last_received_time = time.time()
        print(datetime.datetime.now().time(), "read ", buffer.hex())

        if self.calc_checksum(buffer[0:12]) != buffer[12]:
            print("Invalid checksum!")
            return

        if buffer[0] == 0xA8:
            ints = [i for i in buffer]
            self.print_status(ints)
            ints[1] = ints[1] & 0xfe # clear changed flag
            self._last_status_response = ints

    def print_status(self, ints):
        def p(a, b):
            print((a + ":").ljust(15),  b)
        assert (ints[0] & 0x0f) == 0x08

        p("On/off", "on" if (ints[1] & 0x02) else "off")

        modes = ["cool", "dehumidify", "fan", "auto", "heat"]
        p("Mode", modes[(ints[1] >> 2) & 0b111])

        fans = ["low", "med", "high", "auto", "slow", "low-med", "med-high", "power"]
        p("Fan", fans[ints[1] >> 5])

        p("Horiz swing", "on" if (ints[2] & 0x40) else "off")

        p("Plasma", "on" if (ints[2] & 0x04) else "off")

        room_temp = (ints[7] & 0x3f) / 2 + 10
        p("Room temp", str(room_temp))

        setpoint = float((ints[6] & 0xf) + 15)
        if ints[5] & 0x1:
            setpoint += 0.5
        p("Setpoint", str(setpoint))

        thermistor = (ints[6] >> 4) & 0b11
        p("Thermistor", ["unit", "controller", "2th"][thermistor])

    def send_timed(self):
        # Send capabilities message first.
        if self._last_sent_time is None:
            self.send(b"\xC9\xC4\xEA\x1F\x81\x71\x00\x80\x02\x40\x04\x81")
            return

        # Else send a status message every 30 seconds.
        if self._last_status_response and time.time() - self._last_sent_time > 30:
            status = self._last_status_response
            status[0] = 0xc8
            status[7] = int((25 - 10) * 2) & 0xff # room temp = 25C

            status_new = status[:]

            # Make changes to status_new here, for example:
            status_new[5] |= 0x4 # Outdoor unit on.

            if status != status_new:
                status_new[1] |= 0x01 # changed flag

            self.send(bytes(status_new[0:12]))
            time.sleep(0.1)
            self.send(bytes(status_new[0:12]))

    def send(self, message):
        assert len(message) == 12
        message += bytes([self.calc_checksum(message)])

        print(datetime.datetime.now().time(), "write", message.hex())
        self._serial.write(message)
        self._serial.flush()

        self._last_sent_time = time.time()

        # Read our own message back. Only works if this is a single-wire connection.
        read_msg = b""
        while len(read_msg) < 13:
            read_msg += self._serial.read(1)
        if read_msg != message:
            print("Didn't match:", read_msg, message)

if len(sys.argv) != 2:
    print("Usage: python3 ac-emulator.py /dev/ttyUSB0")
    exit(1)

serial_port = sys.argv[1]
emulator = ACEmulator(serial_port)
emulator.loop()

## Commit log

2023-06-18 Minor controller improvements (avoid spurious state changes, minor code optimization)
    [lg-controller.h]
2023-07-01 Add SVG schematic
2023-07-01 Add higher quality schematic.png
2023-07-01 Add pcb-design.svg
2023-07-11 Add BOM and placement CSV files for PCB, fixes #1
    [pcb-bom.csv, pcb-placement.csv]
2023-07-21 Add ESPHome uptime sensor
2023-11-04 Ignore room temperature from unit if using external sensor. Fixes #10
    [lg-controller.h]
2023-11-04 Make controller initialization match LG controller better
    It now sets the request-settings flag that the LG controller also sets when it's powered on.
    This also handles the settings-batch messages from the AC without (incorrectly) reporting errors.
    [lg-controller.h]
2023-11-05 Add vertical vane setting and YAML option to set installer setting 15 (for heating mode).
    This required some refactoring to allow sending/processing non-status message types.
2023-11-06 changed minimum temperature setpoint from 18°C to 16°C
2023-11-07 added hardware-tiny pcb with kicad 6 and production files (setup for jlcpcb assembly)
    [bom.csv, designators.csv, lg_hvac_esp32.kicad_pcb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]
2023-11-08 Mention new hardware-tiny PCB in the readme
2023-11-10 - added support for parsing & storing capabilities - dynamically show only supported features - support airflow selection of up to 4 vanes - installer settings in UI to fine-tune fan speeds for suppo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
2023-11-10 fixed "slow / quiet" fan speed implementation on restarts, added missing "auto mode" capability, removed unneccessary logs and added comments
    [lg-controller.h]
2023-11-11 fixed plasma purifier capability detection
    [lg-controller.h]
2023-11-11 Only expose fan speed settings if ESP value installer setting is available
2023-11-14 fixed bom and updated kicad project to kicad7 #17
    [bom.csv, lg_hvac_esp32.kicad_pcb, lg_hvac_esp32.kicad_sch]
2023-12-17 Document pipe temperature values in protocol.md
2023-12-18 Add pipe temperature sensors
2024-01-14 Add information about reservation/timer fields to protocol.md
2024-01-15 Add more information about timers
2024-02-01 Add link to template sensor example
2024-02-03 Add sleep timer feature (closes #29)
2024-02-03 Update screenshot and add tiny-pcb picture to README
2024-02-03 Improve README. Link to instructions for ordering the PCB.
2024-02-05 Add supported ducted unit (closes #30)
2024-02-11 Replace YAML option for over heating (installer setting 15) with a select
    [lg-controller.h]
2024-02-27 fixes in schematic & bom, removed C3
    [bom.csv, designators.csv, lg_hvac_esp32.kicad_pcb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]
2024-04-27 Fix vane detection issue reported in issue #53 + minor code changes
    [lg-controller.h]
2024-05-11 Add switch and binary sensor for Auto Dry (Auto Clean) feature
2024-06-01 Add explicit uart_id to support configurations with multiple UARTs (fixes #57)
2024-06-19 Make code compatible with ESP-IDF. The main advantage is to be able to use bluetooth proxy to receive BLE temperature sensors
2024-06-22 Use ESPHome interface to check RX pin
2025-01-04 Use 'type: timestamp' for uptime sensor because it's less noisy. Requires a time component to sync time with HA.
2025-05-26 Make temp sensor optional
2025-05-28 Add PCB for Unexpected Maker's FeatherS3.
    [BOM-lg_hvac_esp32.csv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]
2025-08-17 Switch from arduino to esp-idf framework (see #119)
2025-11-20 Fix compatibility with ESPHome 2025.11.0
    [lg-controller.h]
2025-12-24 Support sleep timer for slave controllers (i#136)
2026-01-21 esphome 2026.1.0 callback signature fix
    [lg-controller.h]
2026-10-24 Add 3D-printable case for the FeatherS3 carrier
    Parametric OpenSCAD source, ready-to-print STL and a photo of the
    printed case for the hardware-FeatherS3 carrier with a FeatherS3[D]
    fitted. Dimensions are taken from the KiCad PCB and Unexpected Maker's
    FeatherS3D STEP model.
